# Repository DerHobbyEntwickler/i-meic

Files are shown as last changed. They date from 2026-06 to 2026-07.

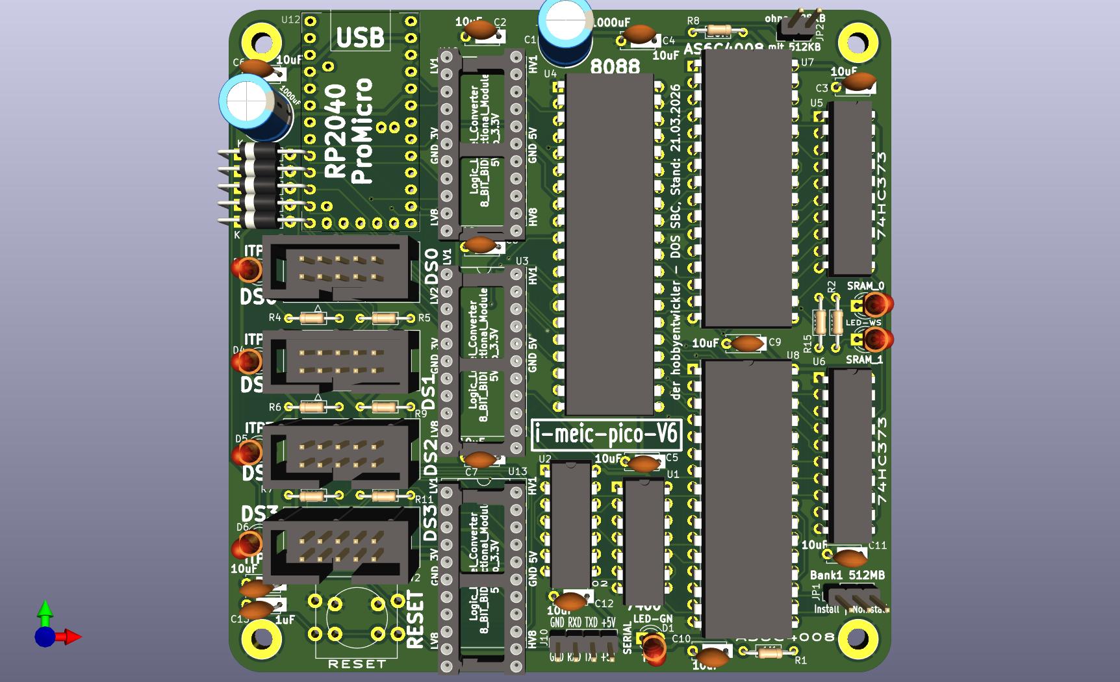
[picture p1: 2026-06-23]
10_i-meic-pico_V6/10_KiCAD/i-meic-pico_V6.jpg

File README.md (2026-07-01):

# i-meic

*(German version: [README_de.md](README_de.md))*

**The i-meic is a modular, expandable single-board computer based on the Intel 8088 CPU.**

> The hardware aims to recreate an IBM PC using the simplest possible means.
> The PC compute core consists of the 8088 CPU and 1 MB of main memory.
> All input/output is handled by a Raspberry Pi RP2040 Pro Micro.
> That is faster, simpler and cheaper than classic peripheral chips.

---

## What does "i-meic" mean?

The name is derived from the German description of the project:

| Letter | Meaning  |
|---|---|
| **i** | (**i**)ntel 8088 |
| **m** | (**m**)odular|
| **e** | (**e**)xpandable |
| **i** | s(**i**)ngle-board |
| **c** | (**c**)omputer |

---

## Concept in brief

Classic 8088 systems require a large number of peripheral chips
(clock generator, bus drivers, interrupt controller, DMA, floppy/HDD
controller, video, keyboard, etc.). The i-meic replaces this entire set of
peripherals with **a single microcontroller**: the Raspberry Pi Pico.

**The PC compute core consists of:**

- **1× Intel 8088 CPU** (16-bit, 20 address lines)
- **2× SRAM of 512 KByte each** → together **1 MByte** (the maximum of the
  8088 address space)

**The Raspberry Pi RP2040 Pro Micro (ARM Cortex-M0+) takes care of:**

- **clock generation** for the 8088 CPU (single-step / clocked operation)
- **loading the BIOS** into SRAM at startup
- the **complete I/O processing** (every read/write access to an I/O port
  is intercepted and serviced by the Pico)
- the **serial connection** to a host PC (screen, keyboard and drives are
  virtualized over the console)
- the **ITP3 interface** for modular expansion

This architecture is unusually powerful because the Pico runs at a
significantly higher clock frequency than the historic 8088 peripherals and
can therefore handle I/O operations very quickly.

---

## System and data flow

This is how a runnable DOS computer is created from source code:

```
   ┌────────────────────────────────────────────────────────────────┐
   │  70_RON-BIOS-NASM …  BIOS.ASM  (8088 assembler, NASM)          │
   │        │  nasm -f bin                                          │
   │        ▼                                                       │
   │     BIOS.BIN  (pure 8088 binary BIOS, segment F800:0000)       │
   │        │  COM2INC  (see 60_FPC_Lazarus/25_LAZ_CLI64_COM2INC)   │
   │        ▼                                                       │
   │     BIOS.INC  (Pascal byte array  BIOS_ARR[…])                 │
   └────────┬───────────────────────────────────────────────────────┘
            │  gets embedded into the Pico firmware
            ▼
   ┌────────────────────────────────────────────────────────────────┐
   │  10_…/20_Lazarus_PICO…  Firmware (Free Pascal / RP2040)        │
   │        │  Lazarus / FPC                                        │
   │        ▼                                                       │
   │     imeic_dos.uf2   →   flash onto the Raspberry Pi Pico       │
   └────────┬───────────────────────────────────────────────────────┘
            │  Pico boots:
            │  1. loads BIOS_ARR into SRAM (F800:0000)
            │  2. clocks the 8088 CPU
            │  3. services all I/O requests (IORQ)
            ▼
   ┌────────────────────────────────────────────────────────────────┐
   │  i-meic board  (8088 + 2×512 KB SRAM)  ←── serial ───┐         │
   └──────────────────────────────────────────────────────┼─────────┘
                                                           │ UART 921600 Bd
   ┌───────────────────────────────────────────────────────▼────────┐
   │  60_…/20_LAZ_Console64 …  CONSOLE64  (host PC, Win64/Linux)    │
   │  provides screen, keyboard and drive images:                  │
   │    BOOTA.IMG  (1.44 MB floppy)     BOOTC.IMG  (8 MB hard disk) │
   └────────────────────────────────────────────────────────────────┘
```

---

## Repository structure

| Folder | Contents |
|---|---|
| [`10_i-meic-pico_V6/`](10_i-meic-pico_V6/) | The actual i-meic board: KiCAD hardware **and** Pico firmware (ARM cross-compiler, I/O interface for DOS) |
| [`10_i-meic-pico_V6/10_KiCAD/`](10_i-meic-pico_V6/10_KiCAD/) | KiCAD project, schematic, layout, Gerber data for PCB manufacturing |
| [`10_i-meic-pico_V6/20_Lazarus_PICO_i-meic-pico_V6_DOS/`](10_i-meic-pico_V6/20_Lazarus_PICO_i-meic-pico_V6_DOS/) | Source code of the Pico firmware for the **ARM cross-compiler** (Free Pascal / Lazarus). The I/O interface here is designed for **DOS**. |
| [`60_FPC_Lazarus/`](60_FPC_Lazarus/) | Host PC tools (Free Pascal / Lazarus) for Windows & Linux |
| [`60_FPC_Lazarus/20_LAZ_Console64_GUI64_Win64_Linux/`](60_FPC_Lazarus/20_LAZ_Console64_GUI64_Win64_Linux/) | **CONSOLE64** – terminal/console program for all i-meic (central tool) |
| [`60_FPC_Lazarus/25_LAZ_CLI64_COM2INC/`](60_FPC_Lazarus/25_LAZ_CLI64_COM2INC/) | **COM2INC** – command-line tool that converts a binary file into a Pascal/NASM include (byte array) |
| [`70_RON-BIOS-NASM_i-meic_WIN_Linux/`](70_RON-BIOS-NASM_i-meic_WIN_Linux/) | **RON-BIOS** – the 8088 BIOS in NASM assembler including build scripts |

>
> **Operating-system variants of the firmware:** For the **i-meic board**
> there are several firmware variants that differ only in the I/O interface –
> currently **DOS** (`…_DOS`) and **CP/M-86** (`…_CPM86`). The hardware and the
> ARM cross-compiler are identical in each case.

---

## Quick start

### 1. Have the PCB manufactured
The ready-to-use Gerber data is located at
`10_i-meic-pico_V6/10_KiCAD/gerber_i-meic-pico_V6.zip` and can be uploaded
directly to a PCB manufacturer. The schematic and layout for further
development are in the same folder as a KiCAD project.

### 2. Flash the Pico firmware
Copy `imeic_dos.uf2` onto the Raspberry Pi Pico (BOOTSEL mode).

### 3. Start the console and connect
Start `CONSOLE64` (in the folder
`60_FPC_Lazarus/20_LAZ_Console64_GUI64_Win64_Linux/bin/`), set the correct
COM port and 921600 baud, then power up the i-meic.

---

## Requirements

- **Hardware:** Intel 8088, 2× SRAM (512 KByte), Raspberry Pi Pico or a
  compatible RP2040 module (footprints for several variants are provided),
  serial connection to the host
- **Software (development):**
  - [KiCAD](https://www.kicad.org/) for the hardware
  - [Lazarus / Free Pascal](https://www.lazarus-ide.org/) including the
    **ARM cross-toolchain** for the RP2040 (the Pico is an ARM
    microcontroller); the firmware runs "bare-metal" on the Pico
  - RP2040 libraries by **Michael Ring** as a basis (included in the `units/`
    folder, **adapted for this project** – see the warning below), original:
    <https://github.com/michael-ring/pico-fpcexamples>
  - [NASM](https://www.nasm.us/) for the BIOS (binaries are included)

---

## Acknowledgements / third parties

- The Free Pascal libraries for the RP2040 come from **Michael Ring**:
  <https://github.com/michael-ring/pico-fpcexamples>. They were an
  **important basis** for this Pico/RP2040 variant.
  ⚠️ The libraries shipped in the `units/` folder have been **modified and
  adapted** for this project and **must not** be replaced by the current
  upstream version (otherwise compilation errors will occur).
- **NASM** is used to assemble the 8088 BIOS (see `LICENSE_NASM.TXT`).

---

## License

This project is licensed under the **GNU General Public License v3.0** – see
[`LICENSE`](LICENSE). The BIOS and COM2INC additionally include the NASM
license (`LICENSE_NASM.TXT`) for the bundled NASM binaries.

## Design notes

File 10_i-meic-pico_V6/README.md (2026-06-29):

# 10_i-meic-pico_V6 — The i-meic board (hardware & firmware)

This folder contains **one complete i-meic variant**: the hardware (KiCAD)
and the matching Pico firmware for DOS operation.

The suffix **`pico_V6`** denotes hardware revision 6 of the board, in which
all I/O is handled by a **Raspberry Pi Pico (RP2040)**.

*(Deutsche Version: [README_de.md](README_de.md))*

## Contents

| Subfolder | Description |
|---|---|
| [`10_KiCAD/`](10_KiCAD/) | KiCAD project: schematic, PCB layout, Gerber data and component library. The PCB can be ordered **and** developed further here. |
| [`20_Lazarus_PICO_i-meic-pico_V6_DOS/`](20_Lazarus_PICO_i-meic-pico_V6_DOS/) | Source of the **Pico firmware** for the **ARM cross-compiler** (Free Pascal / Lazarus, "bare-metal" on the RP2040). The I/O interface here is built for **DOS**. Produces the `imeic_dos.uf2` for flashing the Pico. |

> **About the firmware folder name:** `Lazarus_PICO` refers to the Free
> Pascal / Lazarus **cross-compiler for the ARM core** of the RP2040 (the
> Pico is an ARM microcontroller, not x86). The suffix `…_DOS` refers to the
> **functionality of the I/O interface** for the SBC, which is built for DOS.
>
> **Further operating-system variant (same board):** For the same board there
> is a version with an I/O interface for **CP/M-86**
> (`Lazarus_PICO_i-meic-pico_V6_CPM86`). The hardware and the ARM
> cross-compiler stay the same; only the I/O functionality is tailored to the
> respective operating system.

## How it fits together

The hardware from `10_KiCAD` and the firmware from
`20_Lazarus_PICO_i-meic-pico_V6_DOS` belong directly together:

1. The PCB is manufactured according to the KiCAD/Gerber data and populated.
2. The firmware is compiled and flashed onto the Raspberry Pi Pico.
3. At startup the Pico loads the BIOS into the SRAM, clocks the 8088 CPU and
   services all of its I/O.

Screen, keyboard and drives are provided over the serial interface by the
host program **CONSOLE64**
(`60_FPC_Lazarus/20_LAZ_Console64_GUI64_Win64_Linux/`).

> The BIOS used here is built from the folder
> `70_RON-BIOS-NASM_i-meic_WIN_Linux/` and embedded into the firmware as
> `BIOS.INC`.

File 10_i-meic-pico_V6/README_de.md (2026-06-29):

# 10_i-meic-pico_V6 — Das i-meic-Board (Hardware & Firmware)

*(English version: [README.md](README.md))*

Dieser Ordner enthält **eine vollständige i-meic-Variante**: die Hardware
(KiCAD) und die dazu passende Pico-Firmware für den DOS-Betrieb.

Der Zusatz **`pico_V6`** bezeichnet die Hardware-Revision 6 des Boards, bei
der die gesamte I/O über einen **Raspberry Pi Pico (RP2040)** läuft.

## Inhalt

| Unterordner | Beschreibung |
|---|---|
| [`10_KiCAD/`](10_KiCAD/) | KiCAD-Projekt: Schaltplan, Platinen-Layout, Gerber-Daten und Bauteil-Bibliothek. Hier kann die Leiterplatte in Auftrag gegeben **und** weiterentwickelt werden. |
| [`20_Lazarus_PICO_i-meic-pico_V6_DOS/`](20_Lazarus_PICO_i-meic-pico_V6_DOS/) | Quelltext der **Pico-Firmware** für den **ARM-Cross-Compiler** (Free Pascal / Lazarus, „bare-metal" auf dem RP2040). Die I/O-Schnittstelle ist hier für **DOS** ausgelegt. Erzeugt die `imeic_dos.uf2` zum Flashen des Pico. |

> **Zur Namensgebung des Firmware-Ordners:** `Lazarus_PICO` steht für den
> Free-Pascal-/Lazarus-**Cross-Compiler für den ARM-Kern** des RP2040 (der
> Pico ist ein ARM-Mikrocontroller, kein x86). Der Zusatz `…_DOS` bezieht
> sich auf die **Funktionalität der I/O-Schnittstelle** für den SBC, die für
> DOS erstellt ist.
>
> **Weitere Betriebssystem-Variante (gleiches Board):** Für dasselbe Board
> existiert eine Version mit I/O-Schnittstelle für **CP/M-86**
> (`Lazarus_PICO_i-meic-pico_V6_CPM86`). Hardware und ARM-Cross-Compiler
> bleiben gleich, nur die I/O-Funktionalität ist auf das jeweilige
> Betriebssystem zugeschnitten.

## Zusammenspiel

Die Hardware aus `10_KiCAD` und die Firmware aus
`20_Lazarus_PICO_i-meic-pico_V6_DOS` gehören direkt zusammen:

1. Die Leiterplatte wird nach den KiCAD-/Gerber-Daten gefertigt und bestückt.
2. Die Firmware wird übersetzt und auf den Raspberry Pi Pico geflasht.
3. Der Pico lädt beim Start das BIOS in den SRAM, taktet die 8088-CPU und
   bedient deren gesamte I/O.

Bildschirm, Tastatur und Laufwerke werden über die serielle Schnittstelle
vom Host-Programm **CONSOLE64**
(`60_FPC_Lazarus/20_LAZ_Console64_GUI64_Win64_Linux/`) bereitgestellt.

> Das hier verwendete BIOS wird aus dem Ordner
> `70_RON-BIOS-NASM_i-meic_WIN_Linux/` gebaut und als `BIOS.INC` in die
> Firmware eingebettet.

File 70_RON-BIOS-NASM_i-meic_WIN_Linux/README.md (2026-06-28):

# 70_RON-BIOS-NASM_i-meic_WIN_Linux — RON-BIOS (8086 BIOS)

The **RON-BIOS** is the BIOS of the i-meic, written in **8086 assembly for
NASM**. It is assembled into a binary BIOS and then embedded into the Pico
firmware, which loads it into the SRAM at startup.

- Target processor: **8086** (`BITS 16`, `CPU 8086`)
- BIOS segment: **`F800:0000`**, stack at `FF00`
- Builds on **Windows and Linux** (NASM binaries are included)

*(Deutsche Version: [README_de.md](README_de.md))*

## Structure

The BIOS is built modularly from several assembly files that are combined in
`BIOS.ASM`:

| File | Contents |
|---|---|
| `BIOS.ASM` | Main/entry file, includes the modules. |
| `BDA.ASM` | BIOS Data Area. |
| `EQUDISK.ASM` | Constants/definitions for drives. |
| `INT08.ASM` | Timer interrupt (system tick). |
| `INT10.ASM` | Video services (screen output). |
| `INT13.ASM` | Floppy/hard-disk services. |
| `INT16.ASM` | Keyboard services. |
| `INT1A.ASM` | Time/date (RTC). |
| `INT02.ASM`, `INT18.ASM`, `INT1D.txt`, `INT33.ASM` | Further interrupts (incl. mouse, INT 33h). |
| `VGABIOS.ASM` | Video-BIOS part. |
| `DEBUG.ASM` | Debugging helpers. |
| `BIOS.INC` | Generated include (intermediate state, built via COM2INC). |
| `BIOS.BIN` | **Finished binary BIOS** (result of NASM). |

## Bundled tools

| File | Purpose |
|---|---|
| `nasm.exe` / `nasm` | NASM assembler for Windows and Linux. |
| `COM2INC.exe` / `COM2INC` | Converts `BIOS.BIN` into `BIOS.INC` (byte array). |
| `run_win.bat` | Build script for Windows. |
| `run_linux.sh` | Build script for Linux. |
| `LICENSE_NASM.TXT` | License of NASM. |

## Building the BIOS

**Windows:** run `run_win.bat`.
**Linux:** run `run_linux.sh`.

In essence both perform the same steps:

```
nasm -f bin BIOS.ASM -o BIOS.BIN          # assemble the 8086 BIOS
COM2INC BIOS.BIN BIOS.INC Laenge_BIOS_Array BIOS_ARR   # convert to byte array
```

Afterwards `BIOS.INC` is copied into the Pico firmware under
`10_i-meic-pico_V6/20_Lazarus_PICO_i-meic-pico_V6_DOS/20_i-meic-pico_V6_DOS/`
(the Windows script does this automatically). Then recompile the firmware so
that the updated BIOS takes effect.

> **Connection to the hardware:** The I/O command codes defined in the BIOS
> (e.g. `IORQ_CONIN`, `IORQ_READ`, `IORQ_VIDEO_SEND`) correspond to the
> functions serviced by the Pico firmware. The BIOS and firmware must
> therefore match each other.

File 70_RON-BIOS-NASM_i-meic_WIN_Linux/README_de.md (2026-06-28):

# 70_RON-BIOS-NASM_i-meic_WIN_Linux — RON-BIOS (8086-BIOS)

*(English version: [README.md](README.md))*

Das **RON-BIOS** ist das BIOS des i-meic, geschrieben in **8086-Assembler
für NASM**. Es wird zu einem Binär-BIOS übersetzt und anschließend in die
Pico-Firmware eingebettet, die es beim Start in den SRAM lädt.

- Zielprozessor: **8086** (`BITS 16`, `CPU 8086`)
- BIOS-Segment: **`F800:0000`**, Stack bei `FF00`
- Build unter **Windows und Linux** (NASM-Binaries liegen bei)

## Aufbau

Das BIOS ist modular aus mehreren Assembler-Dateien aufgebaut, die in
`BIOS.ASM` zusammengeführt werden:

| Datei | Inhalt |
|---|---|
| `BIOS.ASM` | Haupt-/Einstiegsdatei, bindet die Module ein. |
| `BDA.ASM` | BIOS Data Area. |
| `EQUDISK.ASM` | Konstanten/Definitionen für Laufwerke. |
| `INT08.ASM` | Timer-Interrupt (System-Tick). |
| `INT10.ASM` | Video-Dienste (Bildschirmausgabe). |
| `INT13.ASM` | Disketten-/Festplatten-Dienste. |
| `INT16.ASM` | Tastatur-Dienste. |
| `INT1A.ASM` | Uhrzeit/Datum (RTC). |
| `INT02.ASM`, `INT18.ASM`, `INT1D.txt`, `INT33.ASM` | Weitere Interrupts (u. a. Maus, INT 33h). |
| `VGABIOS.ASM` | Video-BIOS-Anteil. |
| `DEBUG.ASM` | Debug-Hilfen. |
| `BIOS.INC` | Erzeugtes Include (Zwischenstand, wird per COM2INC gebaut). |
| `BIOS.BIN` | **Fertiges Binär-BIOS** (Ergebnis von NASM). |

## Mitgelieferte Werkzeuge

| Datei | Zweck |
|---|---|
| `nasm.exe` / `nasm` | NASM-Assembler für Windows bzw. Linux. |
| `COM2INC.exe` / `COM2INC` | Wandelt `BIOS.BIN` in `BIOS.INC` (Byte-Array). |
| `run_win.bat` | Build-Skript für Windows. |
| `run_linux.sh` | Build-Skript für Linux. |
| `LICENSE_NASM.TXT` | Lizenz von NASM. |

## BIOS bauen

**Windows:** `run_win.bat` ausführen.
**Linux:** `run_linux.sh` ausführen.

Beide führen im Kern dieselben Schritte aus:

```
nasm -f bin BIOS.ASM -o BIOS.BIN          # 8086-BIOS assemblieren
COM2INC BIOS.BIN BIOS.INC Laenge_BIOS_Array BIOS_ARR   # in Byte-Array wandeln
```

Anschließend wird `BIOS.INC` in die Pico-Firmware unter
`10_i-meic-pico_V6/20_Lazarus_PICO_i-meic-pico_V6_DOS/20_i-meic-pico_V6_DOS/`
kopiert (das Windows-Skript erledigt das automatisch). Danach die Firmware
neu übersetzen, damit das aktualisierte BIOS wirksam wird.

> **Verbindung zur Hardware:** Die im BIOS definierten I/O-Befehlscodes
> (z. B. `IORQ_CONIN`, `IORQ_READ`, `IORQ_VIDEO_SEND`) entsprechen den
> Funktionen, die die Pico-Firmware bedient. BIOS und Firmware müssen daher
> zueinander passen.

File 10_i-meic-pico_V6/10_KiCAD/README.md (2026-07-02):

# 10_KiCAD — Hardware design of the i-meic board (KiCAD)

This folder contains everything needed to **have the i-meic PCB
manufactured** and to **develop the hardware further**.

*(Deutsche Version: [README_de.md](README_de.md))*

## Most important files

| File / folder | Purpose |
|---|---|
| `gerber_i-meic-pico_V6.zip` | **Fabrication data (Gerber + drill).** Can be uploaded directly to a PCB manufacturer. |
| `i-meic-pico_V6.pdf` | Schematic / layout as PDF for viewing and printing. |
| `i-meic-pico_V6.svg` | Vector view of the board. |
| `i-meic-pico_V6.jpg` | Image of the board for a quick overview. |
| `i-meic-pico_V6/` | The actual **KiCAD project** (see below). |

## KiCAD project folder `i-meic-pico_V6/`

| File | Meaning |
|---|---|
| `i-meic-pico_V6.kicad_pro` | KiCAD project file (open the project with this). |
| `i-meic-pico_V6.kicad_sch` | Schematic. |
| `i-meic-pico_V6.kicad_pcb` | PCB layout. |
| `i-meic-pico_V6.kicad_prl` | Local project settings. |
| `board-library/` | **Project-specific component library** with symbols (`.kicad_sym`) and footprints (`.pretty/*.kicad_mod`) – for RP2040 modules, SRAM, LCDs, ITP3 connectors, switches and more. |

## Having the PCB manufactured

1. Upload `gerber_i-meic-pico_V6.zip` unchanged to a PCB manufacturer.
2. Choose the usual parameters (e.g. 2 layers, 1.6 mm, HASL/ENIG).
3. After receiving the board, populate it according to the schematic.

## Developing further

Open the project with **KiCAD** via `i-meic-pico_V6.kicad_pro`. For the
project-specific parts to load correctly, keep the `board-library/` folder as
a library path relative to the project.

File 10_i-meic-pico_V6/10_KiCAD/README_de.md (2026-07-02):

# 10_KiCAD — Hardware-Design des i-meic-Boards (KiCAD)

*(English version: [README.md](README.md))*

Hier liegen alle Dateien, um die Leiterplatte des i-meic **fertigen zu
lassen** und um die Hardware **selbst weiterzuentwickeln**.

## Wichtigste Dateien

| Datei / Ordner | Zweck |
|---|---|
| `gerber_i-meic-pico_V6.zip` | **Fertigungsdaten (Gerber + Bohrdaten).** Direkt beim Leiterplattenhersteller hochladbar. |
| `i-meic-pico_V6.pdf` | Schaltplan / Layout als PDF zum Ansehen und Drucken. |
| `i-meic-pico_V6.svg` | Vektor-Ansicht des Boards. |
| `i-meic-pico_V6.jpg` | Bild des Boards zur schnellen Übersicht. |
| `i-meic-pico_V6/` | Das eigentliche **KiCAD-Projekt** (siehe unten). |

## KiCAD-Projektordner `i-meic-pico_V6/`

| Datei | Bedeutung |
|---|---|
| `i-meic-pico_V6.kicad_pro` | KiCAD-Projektdatei (hiermit das Projekt öffnen). |
| `i-meic-pico_V6.kicad_sch` | Schaltplan. |
| `i-meic-pico_V6.kicad_pcb` | Platinen-Layout. |
| `i-meic-pico_V6.kicad_prl` | Lokale Projekteinstellungen. |
| `board-library/` | **Projekteigene Bauteil-Bibliothek** mit Symbolen (`.kicad_sym`) und Footprints (`.pretty/*.kicad_mod`) – u. a. für RP2040-Module, SRAM, LCDs, ITP3-Stecker, Schalter und mehr. |

## Leiterplatte fertigen lassen

1. `gerber_i-meic-pico_V6.zip` unverändert beim Leiterplattenhersteller
   hochladen.
2. Übliche Parameter wählen (z. B. 2 Lagen, 1,6 mm, HASL/ENIG).
3. Nach Erhalt der Platine gemäß Schaltplan bestücken.

## Weiterentwickeln

Das Projekt mit **KiCAD** über `i-meic-pico_V6.kicad_pro` öffnen. Damit die
projekteigenen Bauteile korrekt geladen werden, sollte der Ordner
`board-library/` als Bibliothekspfad relativ zum Projekt erhalten bleiben.

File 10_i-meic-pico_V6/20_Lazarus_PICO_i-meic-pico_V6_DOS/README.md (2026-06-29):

# 20_Lazarus_PICO_i-meic-pico_V6_DOS — Pico firmware (I/O interface for DOS)

Source of the **firmware for the Raspberry Pi Pico (RP2040)** on the i-meic
board. The firmware turns the 8088 core into a working computer by taking
over all of its input/output.

*(Deutsche Version: [README_de.md](README_de.md))*

## About the folder name

The name consists of two parts:

- **`Lazarus_PICO`** — The RP2040 of the Raspberry Pi Pico is an **ARM
  microcontroller** (Cortex-M0+). This folder therefore contains the source
  for the **Lazarus / Free Pascal cross-compiler for ARM**, i.e.
  "bare-metal" Pascal that runs directly on the Pico (not classic desktop
  Lazarus).
- **`i-meic-pico_V6_DOS`** — refers to the **functionality of the I/O
  interface** for the SBC. This build is made for the **DOS** operating
  system.

> **Sister variant:** For **the same board** there is a version with an I/O
> interface for **CP/M-86**: `Lazarus_PICO_i-meic-pico_V6_CPM86`. The hardware
> and cross-compiler are identical; only the I/O functionality is tailored to
> the respective operating system.

## Tasks of the firmware

- **Hardware initialisation** of the Pico (GPIO, UART, SPI, timer)
- **Loading the BIOS** (`BIOS.INC` → array `BIOS_ARR`) into the SRAM of the
  8088 (segment `F800:0000`)
- **Clocking the 8088 CPU** and controlling RESET, RAM enable, etc.
- **Servicing all I/O requests (IORQ)** of the CPU: console, drives, clock,
  sound, mouse … — here built for **DOS**
- **Serial communication** with the host (default: **921600 baud**)
- **ITP3 expansion bus** (device select DS0–DS3)

## Project structure

| File / folder | Meaning |
|---|---|
| `20_i-meic-pico_V6_DOS/imeic_dos.lpi` | **Lazarus project file** – open the project with this. |
| `20_i-meic-pico_V6_DOS/imeic_dos.lpr` | Main program (firmware startup sequence). |
| `20_i-meic-pico_V6_DOS/GlobalHW_U.PAS` | Hardware layer: GPIO, UART, SPI, data/address bus of the 8088. |
| `20_i-meic-pico_V6_DOS/GlobalDEF_U.PAS` | Global definitions, device constants, data structures. |
| `20_i-meic-pico_V6_DOS/BIOSAdmin_U.PAS` | Management/embedding of the BIOS and the BIOS flash. |
| `20_i-meic-pico_V6_DOS/DeviceManager_U.PAS` | Device management; services the I/O functions for the 8088 CPU. |
| `20_i-meic-pico_V6_DOS/DeviceManager_DOS_IO.INC` | I/O routines specifically for **DOS**. |
| `20_i-meic-pico_V6_DOS/DeviceManager_CPU8088.INC` | CPU-specific routines (8088 bus timing). |
| `20_i-meic-pico_V6_DOS/ITP3_SRV_U.PAS` | Server for the ITP3 expansion bus. |
| `20_i-meic-pico_V6_DOS/UART_U.PAS` | Serial interface. |
| `20_i-meic-pico_V6_DOS/SysTick_U.PAS`, `SysUtils_U.PAS` | Time/utility functions. |
| `20_i-meic-pico_V6_DOS/BIOS.INC` | **Embedded 8086 BIOS** as a byte array (generated from `70_RON-BIOS-NASM…`). |
| `20_i-meic-pico_V6_DOS/bin/imeic_dos.uf2` | **Finished firmware** for flashing the Pico. Also `.elf`, `.hex`, `.bin`. |
| `units/` | **Libraries for the ARM cross-compiler** – see the next section. |

## The `units/` folder (adapted libraries by Michael Ring)

The `units/` subfolder contains the **Free Pascal libraries for the RP2040 by
Michael Ring**. They were an **important foundation** for developing these
cross-compiled sources – without them this Pico/RP2040 variant would not
exist. They provide hardware access (GPIO, UART, SPI, I²C, timer, multicore …)
as well as various drivers (displays such as SSD1306 / ST7735 / ST7789, fonts,
GPS, RTC, etc.) for the ARM cross-compiler.

Original project by Michael Ring:
**https://github.com/michael-ring/pico-fpcexamples**

> ⚠️ **Important:** The units shipped here have been **modified and adapted**
> for this project (for example, some pointer usages were removed). The
> `units/` folder must **not** be replaced with the current version from the
> original repository – otherwise compilation will produce numerous errors.
> **Always use the bundled `units/` folder.**

## Build and flash

1. Open `20_i-meic-pico_V6_DOS/imeic_dos.lpi` in **Lazarus** (the Free Pascal
   **ARM cross-toolchain** for the RP2040 must be set up; the **bundled**
   units from `units/` are required – not the upstream version).
2. Compile the project → this produces `bin/imeic_dos.uf2`.
3. Connect the Pico in **BOOTSEL mode** (hold the BOOTSEL button while
   plugging it in) and copy `imeic_dos.uf2` onto the drive that appears.

## Updating the BIOS

When changing the BIOS, first rebuild it in the folder
`70_RON-BIOS-NASM_i-meic_WIN_Linux/` (produces `BIOS.INC`), copy the
`BIOS.INC` here and recompile the firmware.

> **Note:** The baud rate can be changed in `GlobalHW_U.PAS`; it must match the
> setting in CONSOLE64.

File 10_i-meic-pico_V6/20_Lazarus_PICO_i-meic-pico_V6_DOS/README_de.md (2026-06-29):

# 20_Lazarus_PICO_i-meic-pico_V6_DOS — Pico-Firmware (I/O-Schnittstelle für DOS)

*(English version: [README.md](README.md))*

Quelltext der **Firmware für den Raspberry Pi Pico (RP2040)** auf dem
i-meic-Board. Die Firmware macht aus dem 8086-Kern einen lauffähigen
Rechner, indem sie dessen gesamte Ein-/Ausgabe übernimmt.

## Zur Bedeutung des Ordnernamens

Der Name setzt sich aus zwei Teilen zusammen:

- **`Lazarus_PICO`** — Der RP2040 des Raspberry Pi Pico ist ein
  **ARM-Mikrocontroller** (Cortex-M0+). In diesem Ordner liegt daher der
  Quelltext für den **Lazarus/Free-Pascal-Cross-Compiler für ARM**, also
  „bare-metal"-Pascal, das direkt auf dem Pico läuft (kein klassisches
  Desktop-Lazarus).
- **`i-meic-pico_V6_DOS`** — bezieht sich auf die **Funktionalität der
  I/O-Schnittstelle** für den SBC. Diese Ausführung ist für das
  Betriebssystem **DOS** erstellt.

> **Schwester-Variante:** Für **dasselbe Board** gibt es eine Version mit
> einer I/O-Schnittstelle für **CP/M-86**:
> `Lazarus_PICO_i-meic-pico_V6_CPM86`. Hardware und Cross-Compiler sind
> identisch, nur die I/O-Funktionalität ist auf das jeweilige Betriebssystem
> abgestimmt.

## Aufgaben der Firmware

- **Hardware-Initialisierung** des Pico (GPIO, UART, SPI, Timer)
- **Laden des BIOS** (`BIOS.INC` → Array `BIOS_ARR`) in den SRAM des 8088
  (Segment `F800:0000`)
- **Takten der 8088-CPU** und Steuern von RESET, RAM-Enable usw.
- **Bedienen aller I/O-Anforderungen (IORQ)** der CPU: Konsole, Laufwerke,
  Uhr, Sound, Maus … — hier ausgelegt für **DOS**
- **Serielle Kommunikation** mit dem Host (Standard: **921600 Baud**)
- **ITP3-Erweiterungsbus** (Device-Select DS0–DS3)

## Projektstruktur

| Datei / Ordner | Bedeutung |
|---|---|
| `20_i-meic-pico_V6_DOS/imeic_dos.lpi` | **Lazarus-Projektdatei** – hiermit das Projekt öffnen. |
| `20_i-meic-pico_V6_DOS/imeic_dos.lpr` | Hauptprogramm (Startablauf der Firmware). |
| `20_i-meic-pico_V6_DOS/GlobalHW_U.PAS` | Hardware-Schicht: GPIO, UART, SPI, Daten-/Adressbus des 8088. |
| `20_i-meic-pico_V6_DOS/GlobalDEF_U.PAS` | Globale Definitionen, Gerätekonstanten, Datenstrukturen. |
| `20_i-meic-pico_V6_DOS/BIOSAdmin_U.PAS` | Verwaltung/Einbinden des BIOS und des BIOS-Flash. |
| `20_i-meic-pico_V6_DOS/DeviceManager_U.PAS` | Geräteverwaltung; bedient die I/O-Funktionen für die 8088-CPU. |
| `20_i-meic-pico_V6_DOS/DeviceManager_DOS_IO.INC` | I/O-Routinen speziell für **DOS**. |
| `20_i-meic-pico_V6_DOS/DeviceManager_CPU8088.INC` | CPU-spezifische Routinen (8088-Bustakt). |
| `20_i-meic-pico_V6_DOS/ITP3_SRV_U.PAS` | Server für den ITP3-Erweiterungsbus. |
| `20_i-meic-pico_V6_DOS/UART_U.PAS` | Serielle Schnittstelle. |
| `20_i-meic-pico_V6_DOS/SysTick_U.PAS`, `SysUtils_U.PAS` | Zeit-/Hilfsfunktionen. |
| `20_i-meic-pico_V6_DOS/BIOS.INC` | **Eingebettetes 8088-BIOS** als Byte-Array (aus `70_RON-BIOS-NASM…` erzeugt). |
| `20_i-meic-pico_V6_DOS/bin/imeic_dos.uf2` | **Fertige Firmware** zum Flashen des Pico. Außerdem `.elf`, `.hex`, `.bin`. |
| `units/` | **Bibliotheken für den ARM-Cross-Compiler** – siehe nächster Abschnitt. |

## Der Ordner `units/` (angepasste Bibliotheken von Michael Ring)

Der Unterordner `units/` enthält die **Free-Pascal-Bibliotheken für den
RP2040 von Michael Ring**. Sie waren eine **wichtige Grundlage** für die
Entwicklung dieser Cross-Quelltexte – ohne sie hätte es diese Variante mit
dem Pico/RP2040 nicht gegeben. Sie stellen den Hardware-Zugriff (GPIO, UART,
SPI, I²C, Timer, Multicore …) sowie diverse Treiber (Displays wie SSD1306 /
ST7735 / ST7789, Fonts, GPS, RTC u. a.) für den ARM-Cross-Compiler bereit.

Original-Projekt von Michael Ring:
**https://github.com/michael-ring/pico-fpcexamples**

> ⚠️ **Wichtig:** Die hier mitgelieferten Units wurden für dieses Projekt
> **verändert und angepasst** (z. B. wurden einige Pointer-Nutzungen
> entfernt). Der Ordner `units/` darf **auf keinen Fall** durch die aktuelle
> Version aus dem Original-Repository ersetzt werden – andernfalls kommt es
> beim Übersetzen zu zahlreichen Fehlermeldungen. Es ist **immer der
> mitgelieferte `units/`-Ordner** zu verwenden.

## Bauen und Flashen

1. `20_i-meic-pico_V6_DOS/imeic_dos.lpi` in **Lazarus** öffnen
   (Free-Pascal-**ARM-Cross-Toolchain** für den RP2040 muss eingerichtet
   sein; die **mitgelieferten** Units aus `units/` werden benötigt – nicht
   die Upstream-Version).
2. Projekt übersetzen → es entsteht `bin/imeic_dos.uf2`.
3. Pico im **BOOTSEL-Modus** anschließen (BOOTSEL-Taste beim Einstecken
   halten) und die `imeic_dos.uf2` auf das erscheinende Laufwerk kopieren.

## BIOS aktualisieren

Bei Änderungen am BIOS zuerst im Ordner
`70_RON-BIOS-NASM_i-meic_WIN_Linux/` neu bauen (erzeugt `BIOS.INC`), die
`BIOS.INC` hierher kopieren und die Firmware neu übersetzen.

> **Hinweis:** Die Baudrate lässt sich in `GlobalHW_U.PAS` umstellen; sie
> muss mit der Einstellung in CONSOLE64 übereinstimmen.

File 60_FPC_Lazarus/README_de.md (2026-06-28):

# 60_FPC_Lazarus — Host-PC-Werkzeuge (Free Pascal / Lazarus)

*(English version: [README.md](README.md))*

Dieser Ordner bündelt die **PC-Programme** rund um den i-meic, geschrieben in
**Free Pascal / Lazarus** und lauffähig unter **Windows 64-Bit und Linux**.
Sie laufen auf dem Host-Rechner, nicht auf dem i-meic selbst.

## Inhalt

| Unterordner | Programm | Zweck |
|---|---|---|
| [`20_LAZ_Console64_GUI64_Win64_Linux/`](20_LAZ_Console64_GUI64_Win64_Linux/) | **CONSOLE64** | Zentrales Terminal-/Konsolenprogramm. Stellt dem i-meic über die serielle Schnittstelle Bildschirm, Tastatur und Laufwerks-Images zur Verfügung. **Wird für alle i-meic benötigt.** |
| [`25_LAZ_CLI64_COM2INC/`](25_LAZ_CLI64_COM2INC/) | **COM2INC** | Kommandozeilen-Werkzeug, das eine Binärdatei (z. B. das BIOS) in ein Pascal-/NASM-Include mit einem Byte-Array umwandelt. |

## Hinweis zu den Konsolen

CONSOLE64 ist die hier abgelegte Konsole – es **gibt mehrere Konsolen** für
unterschiedliche i-meic-Varianten, die nach und nach ergänzt werden. Die
Nummerierung (`20_`, `25_`, …) lässt dafür bewusst Platz.

## Bauen

Alle Programme lassen sich mit **Lazarus** über die jeweilige `*.lpi`-Datei
öffnen und übersetzen. Vorkompilierte Binaries (`.exe` für Windows, die
ausführbare Datei ohne Endung für Linux) liegen zur direkten Nutzung bei.

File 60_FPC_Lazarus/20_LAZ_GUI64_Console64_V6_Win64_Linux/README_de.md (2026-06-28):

# 20_LAZ_Console64_GUI64_Win64_Linux — CONSOLE64

*(English version: [README.md](README.md))*

**CONSOLE64** ist das zentrale Host-Programm für den i-meic. Es verbindet
sich über die serielle Schnittstelle mit dem Board und stellt ihm die
gesamte „sichtbare" Peripherie bereit:

- **Bildschirm / Video-Terminal** (mit Codepage-437-Zeichensatz)
- **Tastatur**
- **Laufwerke** als Disk-Images (Diskette und Festplatte)

Ohne diese Konsole hat der i-meic weder Anzeige noch Eingabe – sie wird
daher **für alle i-meic benötigt**. Lauffähig unter **Windows 64-Bit und
Linux** (GUI-Anwendung auf LCL-Basis).

## Ordnerstruktur

| Ordner / Datei | Bedeutung |
|---|---|
| `bin/CONSOLE64.exe` | Ausführbares Programm (Windows). |
| `bin/CONSOLE64` | Ausführbares Programm (Linux). |
| `bin/CONSOLE64.ini` | Konfiguration: COM-Port, Baudrate, Schrift, Sprache, Logging. |
| `bin/IMAGE_FDD/BOOTA.IMG` | Disketten-Image (1,44 MB) – Laufwerk A:. |
| `bin/IMAGE_HDD/BOOTC.IMG` | Festplatten-Image (8 MB) – Laufwerk C:. |
| `src/` | Lazarus-Quelltext. |

### Wichtige Quelldateien (`src/`)

| Datei | Inhalt |
|---|---|
| `CONSOLE64.lpi` / `.lpr` | Lazarus-Projekt und Hauptprogramm. |
| `MainUnit.pas` / `.lfm` | Hauptfenster und Programmlogik. |
| `Unit_CONS.pas` / `.lfm` | Konsolen-/Terminal-Fenster. |
| `Video_Send.INC` | Aufbereitung der Videoausgabe zum/vom i-meic. |
| `Codepage437.INC` | DOS-Zeichensatz (Codepage 437). |
| `Keyboard.INC` | Tastaturbehandlung. |
| `language_u.pas`, `language_de.INC`, `language_en.INC` | Mehrsprachigkeit (Deutsch/Englisch). |
| `synaser/` | Serielle Bibliothek (Synaser) für die COM-Port-Kommunikation. |
| `windos.pas` | Hilfsroutinen. |

## Bedienung

1. Programm starten (`CONSOLE64.exe` bzw. `./CONSOLE64`).
2. In den Einstellungen den richtigen **COM-Port** und die **Baudrate**
   wählen. Die Baudrate muss mit der Firmware übereinstimmen
   (Standard der Firmware: **921600 Baud**).
3. Bei Bedarf die Disk-Images in `IMAGE_FDD/` bzw. `IMAGE_HDD/` zuordnen.
4. Den i-meic mit Strom versorgen – die Konsole zeigt die Ausgabe an und
   leitet Tastatureingaben weiter.

Die Einstellungen werden in `CONSOLE64.ini` gespeichert.

> **Tipp:** Eigene DOS-Disketten/Festplatten lassen sich durch Austauschen
> der `BOOTA.IMG` / `BOOTC.IMG` einbinden (gleiche Image-Größe beibehalten).

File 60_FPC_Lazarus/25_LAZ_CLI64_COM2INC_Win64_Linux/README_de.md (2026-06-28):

# 25_LAZ_CLI64_COM2INC — COM2INC

*(English version: [README.md](README.md))*

**COM2INC** ist ein kleines Kommandozeilen-Werkzeug (Free Pascal / Lazarus),
das eine **Binärdatei in ein Include-File mit einem Byte-Array** umwandelt.
Damit lässt sich z. B. das fertige BIOS-Binär (`BIOS.BIN`) als Pascal-Array
in die Pico-Firmware einbetten.

Lauffähig unter **Windows 64-Bit und Linux**.

## Funktion

```
COM2INC  <Eingabe.BIN>  <Ausgabe.INC>  <Längen-Konstante>  <Array-Name>  [CLEAR]
```

| Parameter | Bedeutung |
|---|---|
| `Eingabe.BIN` | beliebige Binärdatei (z. B. `BIOS.BIN`, `CPD5.COM`). |
| `Ausgabe.INC` | erzeugtes Include mit dem Byte-Array. |
| `Längen-Konstante` | Name der erzeugten Längenkonstante (z. B. `Laenge_BIOS_Array`). |
| `Array-Name` | Name des erzeugten Arrays (z. B. `BIOS_ARR`). |
| `CLEAR` | optional; bereinigt/initialisiert die Ausgabe. |

**Beispiel** (siehe `run_win.bat`):

```
COM2INC.exe CPD5.COM CPD5.INC Laenge_BIOS_Array BIOS_ARR CLEAR
```

Ergebnis ist eine `.INC`-Datei der Form
`BIOS_ARR : array[0..Laenge_BIOS_Array] of Byte = ( … );`, die per
`{$I …}` in den Pascal-Quelltext eingebunden werden kann.

## Inhalt des Ordners

| Datei | Bedeutung |
|---|---|
| `COM2INC.lpi` / `.lpr` | Lazarus-Projekt und Quelltext. |
| `COM2INC.exe` | Ausführbares Programm (Windows). |
| `COM2INC` | Ausführbares Programm (Linux). |
| `CPD5.COM` / `CPD5.INC` | Beispiel: Eingabe-Binär und erzeugtes Include. |
| `run_win.bat` / `run_linux.sh` | Aufruf-Beispiele für Windows bzw. Linux. |
| `LICENSE_NASM.TXT` | Lizenz der mitgelieferten NASM-Komponenten. |

## Bezug zum BIOS

Dasselbe Werkzeug wird im Ordner `70_RON-BIOS-NASM_i-meic_WIN_Linux/`
verwendet, um aus `BIOS.BIN` die `BIOS.INC` für die Firmware zu erzeugen.

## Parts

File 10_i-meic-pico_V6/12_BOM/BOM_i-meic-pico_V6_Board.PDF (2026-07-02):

# Bill of Materials (BOM)

### i-meic-pico_V6 Board

DOS PC with an 8088 single-board computer (SBC)

Project: i-meic – single-board DOS PC As of: Juli 2026 / July 2026 https://github.com/DerHobbyEntwickler/i-meic

Bill of Materials — i-meic-pico_V6 Board | https://github.com/DerHobbyEntwickler/i-meic | Page 1

Processing core: CPU Intel 80C88 + 2× SRAM AS6C4008 (512 KB each, 1 MB total max.)

Line items: 22 · Total parts: 56

Part | Qty | Value | Remarks | Note | Datasheet
C1, C14 | 2 | 470uF/10V or 1000uF/10V | Electrolytic capacitor, radial, D8.0 mm, P3.50 mm | H01 | Datasheet (https://www.reichelt.de/de/de/shop/produkt/elko_radial_1_0_mf_10_v_105_c_low_esr-200069)
C2, C3, C4, C5, C6, C7, C8, C9, C10, C11, C12, C13, C18 | 13 | 1uF/50V or 10uF/50V | Monolithic ceramic capacitor, pitch 2.5 mm to 5 mm | H02 | Datasheet (https://www.conrad.de/de/p/tancap-ct4-0805y105m500a1-keramik-kondensator-tht-1-f-50-v-20-b-x-h-4-2-mm-x-25-mm-1-st-1578616.html)
D1 | 1 | LED green, UART | Light-emitting diode, 3 mm or 5 mm | H03 | Datasheet (https://www.reichelt.de/de/de/shop/produkt/led_3mm_bedrahtet_gruen_50_mcd_60_-361591)
D2, D17 | 2 | LED white, SRAM | Light-emitting diode, 3 mm or 5 mm | — | Datasheet (https://www.reichelt.de/de/de/shop/produkt/led_3mm_bedrahtet_gruen_50_mcd_60_-361591)
D3, D4, D5, D6 | 4 | LED blue, ITP3 | Light-emitting diode, 3 mm or 5 mm | — | Datasheet (https://www.reichelt.de/de/de/shop/produkt/led_3mm_bedrahtet_gruen_50_mcd_60_-361591)
D7, D8, D9, D10, D11 | 5 | 1N4001 | Diode 1N4001 | H04 | Datasheet (https://www.reichelt.de/de/de/shop/produkt/gleichrichterdiode_50_v_1_a_do-41-1723)
J10 | 1 | Connector for serial adapter | Pin header 2.54 mm, single row, 4 pins | H05 | Datasheet (https://www.reichelt.de/de/de/shop/produkt/stiftleisten_2_54_mm_1x36_gerade-119890)
JP1 | 1 | Jumper connector, 3 pins | Pin header 2.54 mm, single row, 3 pins | — | Datasheet (https://www.reichelt.de/de/de/shop/produkt/stiftleisten_2_54_mm_1x36_gerade-119890)
JP2 | 1 | Jumper connector, 2 pins | Pin header 2.54 mm, single row, 2 pins | — | Datasheet (https://www.reichelt.de/de/de/shop/produkt/stiftleisten_2_54_mm_1x36_gerade-119890)
J_DS0, J_DS1, J_DS2, J_DS3 | 4 | Connector for ITP3 cable, dual row | Box header, 10-pin, straight, dual row | H06 | Datasheet (https://www.reichelt.de/de/de/shop/produkt/wannenstecker_10-polig_gerade-22816)
R1 | 1 | 1K | Resistor, carbon film, 1.0 kOhm, 0207, 250 mW, 5 % | H07 | Datasheet (https://www.reichelt.de/de/de/shop/produkt/widerstand_kohleschicht_1_0_kohm_0207_250_mw_5_-1315)
R2, R15 | 2 | 6.8K | Resistor, carbon film, 6.8 kOhm, 0207, 250 mW, 5 % | — | —
R4, R5, R6, R7 | 4 | 2.2K | Resistor, carbon film, 2.2 kOhm, 0207, 250 mW, 5 % | — | —
R8, R9, R11 | 3 | 10K | Resistor, carbon film, 10 kOhm, 0207, 250 mW, 5 % | H08 | —
SW2 | 1 | Reset button | Tact switch, PCB mount, 1 NO contact, 12 x 12 x 4.3 mm | — | Datasheet (https://www.reichelt.de/de/de/shop/produkt/kurzhubtaster_printmontage_1_schliesser_12_x_12_x_4_3_mm-424572)
U1 | 1 | IC 74HC00 | Quad 2-input NAND gate, 2 … 6 V, DIL-14 | H09 | Datasheet (https://www.reichelt.de/de/de/shop/produkt/4-fach_2_eingangs-nand-gatter_2_6_v_dil-14-3119)
U2 | 1 | IC 74HC02 | NOR gate, 2-input, 2 … 6 V, DIL-14 | — | Datasheet (https://www.reichelt.de/de/de/shop/produkt/nor-gate_2-input_2_6_v_dil-14-3121)
U3, U10, U13 | 3 | 8-channel bidirectional logic level shifter (3.3V ↔ 5V) | 8-channel bidirectional logic level shifter module (3.3V ↔ 5V) | — | Datasheet (https://www.ebay.de/itm/263540322019?chn=ps&_ul=DE&google_free_listing_action=view_item)
U4 | 1 | IC CPU 80C88 | CPU Intel 80C88 or compatible | H10 | Datasheet (https://datasheets.chipdb.org/Harris/80c88.pdf)
U5, U6 | 2 | IC 74HC373 | Latch, 3-state, 2 … 6 V, DIL-20 | — | Datasheet (https://www.reichelt.de/de/de/shop/produkt/latch_3-state_2_6_v_dil-20-3206)
U7, U8 | 2 | IC SRAM AS6C4008-55PCN | SRAM, 4 Mb (512 K x 8), 4.5 … 5.5 V, PDIP-32 | H11 | Datasheet 1 (https://www.alliancememory.com/wp-content/uploads/pdf/AS6C4008.pdf) · Datasheet 2 (https://www.reichelt.de/de/de/shop/produkt/sram_4_mb_512_k_x_8_4_5_5_5_v_pdip-32-40090)

### i-meic-pico_V6 Board

DOS PC with an 8088 single-board computer (SBC) https://github.com/DerHobbyEntwickler/i-meic

Bill of Materials — i-meic-pico_V6 Board | https://github.com/DerHobbyEntwickler/i-meic | Page 2
Part | Qty | Value | Remarks | Note | Datasheet
U12 | 1 | RP2040 Pro Micro / Raspberry Pi Pico | RP2040 Pro Micro / Raspberry Pi Pico | H12 | RP2040 Pro Micro Raspberry Pi Pico development board (source: AliExpress)

Blue underlined entries in the "Datasheet" column are clickable links.

### i-meic-pico_V6 Board

DOS PC with an 8088 single-board computer (SBC) https://github.com/DerHobbyEntwickler/i-meic

Bill of Materials — i-meic-pico_V6 Board | https://github.com/DerHobbyEntwickler/i-meic | Page 3

## Notes on the bill of materials

H01 — 470uF/10V or 1000uF/10V
2× electrolytic capacitors used as decoupling capacitors. Values are not critical.

H02 — Ceramic capacitor, 1uF or 10uF
13× decoupling capacitors, values are not critical. For decades a 100 nF decoupling capacitor was used for every IC. Today, ceramic capacitors from 1 uF upward are very cheap. Recommendation: 10 uF is even better.

H03 / H07 — LEDs and their series resistors (carbon film, 1K / 6.8K / 2.2K)
In principle, the resistors listed here are the series (dropping) resistors for the various LEDs. They are classically calculated by subtracting the LED forward voltage from the supply voltage. The resulting voltage, together with a chosen LED current (e.g. 5 mA), is used to calculate the resistor value. In practice, LED quality and typical on-time also matter a great deal.
The two white LEDs (R2, R15) are very bright and need only very little current for normal operation, so a series resistor of 6.8K has proven sufficient here. R1 with 1K as the series resistor for the green UART LED, by contrast, is often somewhat dim – especially since the supply voltage here is only 3.6 V – or a super-bright green LED is used. The 2.2K series resistor for the four blue ITP3 LEDs (R4, R5, R6, R7) has proven itself in practice.

H04 — Diode 1N4001
The value and type of the diode are entirely uncritical.

H05 — Pin header
The various pin headers (with 2, 3 and 4 pins) can be cut from one long 40-pin header. Coloured headers improve orientation but are not strictly necessary.

H06 — Box header (ITP3 cable)
No further text is provided for this note in the source. These are the 10-pin, dual-row box headers (J_DS0…J_DS3) for the ITP3 cables.

H08 — Carbon-film resistors 10K
Pull-up resistors to ensure a constant voltage level. Resistor values are not critical (4.7K … 22K should meet the requirements).

H09 — 74HC00 and 74HC02
Standard 74-series logic. Also relatively uncritical (HC, HCT or LS are possible).

### i-meic-pico_V6 Board

DOS PC with an 8088 single-board computer (SBC) https://github.com/DerHobbyEntwickler/i-meic

Bill of Materials — i-meic-pico_V6 Board | https://github.com/DerHobbyEntwickler/i-meic | Page 4

H10 — CPU Intel 80C88 or compatible
The central CPU IC, the 8088, has become quite rare by now and is somewhat more expensive. Where possible, the CMOS variant should be preferred (lower power consumption, runs cooler). The NMOS variants should also be usable (but this has not yet been tested).
One more note: cheaper components are often available on AliExpress. They were frequently used in these prototypes. However, at least in part, these appear to be used goods. That is not a problem in itself. What can happen is that the contacts are more or less oxidised. If sockets are used (which is recommended), contact difficulties may occur during assembly. In that case, please clean the IC pins (with a glass-fibre pen, carefully with fine sandpaper, or carefully with a small file).

H11 — SRAM AS6C4008-55PCN or pin-compatible IC
Components from German suppliers (such as Reichelt Elektronik) were always of high quality and without complaints, but also noticeably more expensive. On AliExpress they can certainly be obtained more cheaply, but may then be of lower quality (see “One more note” under H10).

H12 — RP2040 Pro Micro / Raspberry Pi Pico
The RP2040 Pro Micro board is considerably smaller than the classic Raspberry Pi Pico. For this reason it was used for this board. Both boards contain an RP2040 and are software-compatible. The source for the RP2040 Pro Micro board is AliExpress.

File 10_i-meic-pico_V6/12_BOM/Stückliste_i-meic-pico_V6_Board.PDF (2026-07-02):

# Stückliste

### i-meic-pico_V6 Board

DOS-PC mit 8088-Einplatinencomputer (SBC)

Projekt: i-meic – Einplatinen-DOS-PC Stand: Juli 2026 / July 2026 https://github.com/DerHobbyEntwickler/i-meic

Stückliste i-meic-pico_V6 Board | https://github.com/DerHobbyEntwickler/i-meic | Seite 1

Rechnerkern: CPU Intel 80C88 + 2× SRAM AS6C4008 (je 512 KB, zusammen 1 MB max.)

Positionen: 22 · Bauteile gesamt: 56

Bauteil | Anzah l | Wert | Bemerkungen | Hinweis | Datenblatt
C1, C14 | 2 | 470uF/10V oder 1000uF/10V | Elektrolytkondensator, radial, D8,0 mm, P3,50 mm | H01 | Datenblatt (https://www.reichelt.de/de/de/shop/produkt/elko_radial_1_0_mf_10_v_105_c_low_esr-200069)
C2, C3, C4, C5, C6, C7, C8, C9, C10, C11, C12, C13, C18 | 13 | 1uF/50V oder 10uF/50V | monolithischer Keramik-Kondensator, Rastermaß 2,5 mm bis 5 mm | H02 | Datenblatt (https://www.conrad.de/de/p/tancap-ct4-0805y105m500a1-keramik-kondensator-tht-1-f-50-v-20-b-x-h-4-2-mm-x-25-mm-1-st-1578616.html)
D1 | 1 | LED Grün, UART | Leuchtdiode, 3 mm oder 5 mm | H03 | Datenblatt (https://www.reichelt.de/de/de/shop/produkt/led_3mm_bedrahtet_gruen_50_mcd_60_-361591)
D2, D17 | 2 | LED Weiß, SRAM | Leuchtdiode, 3 mm oder 5 mm | — | Datenblatt (https://www.reichelt.de/de/de/shop/produkt/led_3mm_bedrahtet_gruen_50_mcd_60_-361591)
D3, D4, D5, D6 | 4 | LED Blau, ITP3 | Leuchtdiode, 3 mm oder 5 mm | — | Datenblatt (https://www.reichelt.de/de/de/shop/produkt/led_3mm_bedrahtet_gruen_50_mcd_60_-361591)
D7, D8, D9, D10, D11 | 5 | 1N4001 | Diode 1N4001 | H04 | Datenblatt (https://www.reichelt.de/de/de/shop/produkt/gleichrichterdiode_50_v_1_a_do-41-1723)
J10 | 1 | Stecker für seriellen Adapter | Stiftleiste 2,54 mm, einreihig, 4 Stifte | H05 | Datenblatt (https://www.reichelt.de/de/de/shop/produkt/stiftleisten_2_54_mm_1x36_gerade-119890)
JP1 | 1 | Stecker für Jumper, 3 Stifte | Stiftleiste 2,54 mm, einreihig, 3 Stifte | — | Datenblatt (https://www.reichelt.de/de/de/shop/produkt/stiftleisten_2_54_mm_1x36_gerade-119890)
JP2 | 1 | Stecker für Jumper, 2 Stifte | Stiftleiste 2,54 mm, einreihig, 2 Stifte | — | Datenblatt (https://www.reichelt.de/de/de/shop/produkt/stiftleisten_2_54_mm_1x36_gerade-119890)
J_DS0, J_DS1, J_DS2, J_DS3 | 4 | Stecker für ITP3-Kabel, zweireihig | Wannenstecker, 10-polig, gerade, zweireihig | H06 | Datenblatt (https://www.reichelt.de/de/de/shop/produkt/wannenstecker_10-polig_gerade-22816)
R1 | 1 | 1K | Widerstand, Kohleschicht, 1,0 kOhm, 0207, 250 mW, 5 % | H07 | Datenblatt (https://www.reichelt.de/de/de/shop/produkt/widerstand_kohleschicht_1_0_kohm_0207_250_mw_5_-1315)
R2, R15 | 2 | 6,8K | Widerstand, Kohleschicht, 6,8 kOhm, 0207, 250 mW, 5 % | — | —
R4, R5, R6, R7 | 4 | 2,2K | Widerstand, Kohleschicht, 2,2 kOhm, 0207, 250 mW, 5 % | — | —
R8, R9, R11 | 3 | 10K | Widerstand, Kohleschicht, 10 kOhm, 0207, 250 mW, 5 % | H08 | —
SW2 | 1 | Reset-Taster | Kurzhubtaster, Printmontage, 1 Schließer, 12 x 12 x 4,3 mm | — | Datenblatt (https://www.reichelt.de/de/de/shop/produkt/kurzhubtaster_printmontage_1_schliesser_12_x_12_x_4_3_mm-424572)
U1 | 1 | IC 74HC00 | 4-fach 2-Eingangs-NAND-Gatter, 2 … 6 V, DIL-14 | H09 | Datenblatt (https://www.reichelt.de/de/de/shop/produkt/4-fach_2_eingangs-nand-gatter_2_6_v_dil-14-3119)
U2 | 1 | IC 74HC02 | NOR-Gatter, 2-Eingang, 2 … 6 V, DIL-14 | — | Datenblatt (https://www.reichelt.de/de/de/shop/produkt/nor-gate_2-input_2_6_v_dil-14-3121)
U3, U10, U13 | 3 | 8-Kanal-Bidirektionaler Logikpegelwandler (3,3V ↔ 5V) | 8-Kanal-bidirektionales Logikpegelwandler-Modul (3,3V ↔ 5V) | — | Datenblatt (https://www.ebay.de/itm/263540322019?chn=ps&_ul=DE&google_free_listing_action=view_item)
U4 | 1 | IC CPU 80C88 | CPU Intel 80C88 oder kompatibel | H10 | Datenblatt (https://datasheets.chipdb.org/Harris/80c88.pdf)
U5, U6 | 2 | IC 74HC373 | Latch, 3-State, 2 … 6 V, DIL-20 | — | Datenblatt (https://www.reichelt.de/de/de/shop/produkt/latch_3-state_2_6_v_dil-20-3206)
U7, U8 | 2 | IC SRAM AS6C4008-55PCN | SRAM, 4 Mb (512 K x 8), 4,5 … 5,5 V, PDIP-32 | H11 | Datenblatt 1 (https://www.alliancememory.com/wp-content/uploads/pdf/AS6C4008.pdf) · Datenblatt 2 (https://www.reichelt.de/de/de/shop/produkt/sram_4_mb_512_k_x_8_4_5_5_5_v_pdip-32-40090)

### i-meic-pico_V6 Board

DOS-PC mit 8088-Einplatinencomputer (SBC) https://github.com/DerHobbyEntwickler/i-meic

Stückliste i-meic-pico_V6 Board | https://github.com/DerHobbyEntwickler/i-meic | Seite 2
Bauteil | Anzah l | Wert | Bemerkungen | Hinweis | Datenblatt
U12 | 1 | RP2040 Pro Micro / Raspberry Pi Pico | RP2040 Pro Micro / Raspberry Pi Pico | H12 | RP2040 Pro Micro Raspberry Pi Pico Development Board (Bezug: AliExpress)

Blau unterstrichene Einträge in der Spalte „Datenblatt“ sind anklickbare Links.

### i-meic-pico_V6 Board

DOS-PC mit 8088-Einplatinencomputer (SBC) https://github.com/DerHobbyEntwickler/i-meic

Stückliste i-meic-pico_V6 Board | https://github.com/DerHobbyEntwickler/i-meic | Seite 3

## Hinweise zur Stückliste

H01 — 470uF/10V oder 1000uF/10V
2× Elektrolytkondensator, Stützkondensatoren. Werte unkritisch.

H02 — Keramik-Kondensator, 1uF oder 10uF
13× Stützkondensatoren, Werte unkritisch. In den letzten Jahrzehnten verwendete man für jeden IC einen Stützkondensator von 100 nF. Heutzutage sind Keramik-Kondensatoren ab 1 uF sehr günstig. Empfehlung: 10 uF sind noch besser.

H03 / H07 — LEDs und ihre Vorwiderstände (Kohleschicht, 1K / 6,8K / 2,2K)
Grundsätzlich sind die hier angegebenen Widerstände die Vorwiderstände für diverse Leuchtdioden. Sie werden klassischerweise berechnet, indem die Versorgungsspannung minus die Flussspannung der LED gerechnet wird. Die daraus resultierende Spannung dient bei vorgegebenem Strom durch die Leuchtdiode (z. B. 5 mA) zur Berechnung des Widerstandes. Die Praxis zeigt, dass die Qualität der Leuchtdioden und die typische Leuchtdauer ebenfalls sehr wichtig sind.
So sind die beiden weißen LEDs (R2, R15) sehr hell und benötigen nur sehr wenig Strom zum regulären Betrieb. Daher hat sich hier der Vorwiderstand von 6,8K als ausreichend bewährt. R1 mit 1K als Vorwiderstand für die grüne UART-LED ist hingegen oft etwas dunkel, zumal die Versorgungsspannung hier nur 3,6 V beträgt – oder es wird eine superhelle grüne LED genutzt. Der Vorwiderstand von 2,2K für die 4 blauen ITP3-LEDs (R4, R5, R6, R7) hat sich in der Praxis bewährt.

H04 — Diode 1N4001
Wert und Typ der Diode sind vollkommen unkritisch.

H05 — Stiftleiste
Die diversen Stiftleisten (mit 2, 3 und 4 Stiften) können von einer langen 40-poligen Stiftleiste abgeschnitten werden. Farbige Stiftleisten verbessern die Orientierung, sind aber nicht unbedingt erforderlich.

H06 — Wannenstecker (ITP3-Kabel)
In der Vorlage ist zu diesem Hinweis kein weiterer Text hinterlegt. Es handelt sich um die 10-poligen, zweireihigen Wannenstecker (J_DS0…J_DS3) für die ITP3-Kabel.

H08 — Kohleschichtwiderstände 10K
Pull-up-Widerstände zum Gewährleisten eines konstanten Spannungspegels. Widerstandswerte sind unkritisch (4,7K … 22K sollten den Anforderungen genügen).

H09 — 74HC00 und 74HC02
Standard-74er-Baureihe. Ebenfalls relativ unkritisch (HC, HCT oder LS möglich).

### i-meic-pico_V6 Board

DOS-PC mit 8088-Einplatinencomputer (SBC) https://github.com/DerHobbyEntwickler/i-meic

Stückliste i-meic-pico_V6 Board | https://github.com/DerHobbyEntwickler/i-meic | Seite 4

H10 — CPU Intel 80C88 oder kompatibel
Der zentrale CPU-IC 8088 ist inzwischen schon recht selten geworden und etwas teurer. Wenn möglich sollte die CMOS-Variante bevorzugt werden (weniger Energieverbrauch und wird nicht so warm). Aber auch die NMOS-Varianten sollten nutzbar sein (ist aber noch nicht getestet worden).
Noch ein Hinweis: Bei AliExpress sind oft günstigere Bauelemente beziehbar. In diesen Prototypen wurden sie oft genutzt. Es scheint sich hier (zumindest teilweise) um gebrauchte Ware zu handeln. Das ist nicht weiter kritisch. Was dann vorkommen kann: Die Kontakte sind mehr oder weniger oxidiert. Wenn Fassungen genutzt werden (was zu empfehlen ist), kann es beim Einbau zu Kontaktschwierigkeiten kommen. Dann bitte die IC-Anschlüsse reinigen (mit Glasfaserstift, vorsichtig mit feinem Sandpapier oder vorsichtig mit einer kleinen Feile).

H11 — SRAM AS6C4008-55PCN oder pinkompatibler IC
Die Bauelemente von deutschen Lieferanten (wie z. B. Reichelt Elektronik) waren immer qualitativ hochwertig und ohne Beanstandungen, dafür aber auch deutlich teurer. Bei AliExpress bekommt man sie sicher günstiger, sie können dann aber auch eine geringere Qualität aufweisen (siehe „Noch ein Hinweis“ unter H10).

H12 — RP2040 Pro Micro / Raspberry Pi Pico
Das Board RP2040 Pro Micro ist wesentlich kleiner als der klassische Raspberry Pi Pico. Aus diesem Grund wurde es für dieses Board genutzt. Beide Boards enthalten einen RP2040 und sind softwareseitig funktionskompatibel. Bezugsquelle für das RP2040 Pro Micro Board ist AliExpress.

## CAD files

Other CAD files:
10_i-meic-pico_V6/20_Lazarus_PICO_i-meic-pico_V6_DOS/units/boot2_adafruit_itsybitsy_rp2040.obj
10_i-meic-pico_V6/20_Lazarus_PICO_i-meic-pico_V6_DOS/units/flash.c-debug.obj
10_i-meic-pico_V6/20_Lazarus_PICO_i-meic-pico_V6_DOS/units/multicore.c-debug.obj
10_i-meic-pico_V6/20_Lazarus_PICO_i-meic-pico_V6_DOS/units/gpio.c-debug.obj
10_i-meic-pico_V6/20_Lazarus_PICO_i-meic-pico_V6_DOS/units/timeout_helper.c-debug.obj
10_i-meic-pico_V6/20_Lazarus_PICO_i-meic-pico_V6_DOS/units/spi.c-debug.obj
10_i-meic-pico_V6/20_Lazarus_PICO_i-meic-pico_V6_DOS/units/clocks.c-debug.obj
10_i-meic-pico_V6/20_Lazarus_PICO_i-meic-pico_V6_DOS/units/boot2_pimoroni_tiny2040.obj
10_i-meic-pico_V6/20_Lazarus_PICO_i-meic-pico_V6_DOS/units/platform.c-debug.obj
10_i-meic-pico_V6/20_Lazarus_PICO_i-meic-pico_V6_DOS/units/boot2_adafruit_feather_rp2040.obj
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

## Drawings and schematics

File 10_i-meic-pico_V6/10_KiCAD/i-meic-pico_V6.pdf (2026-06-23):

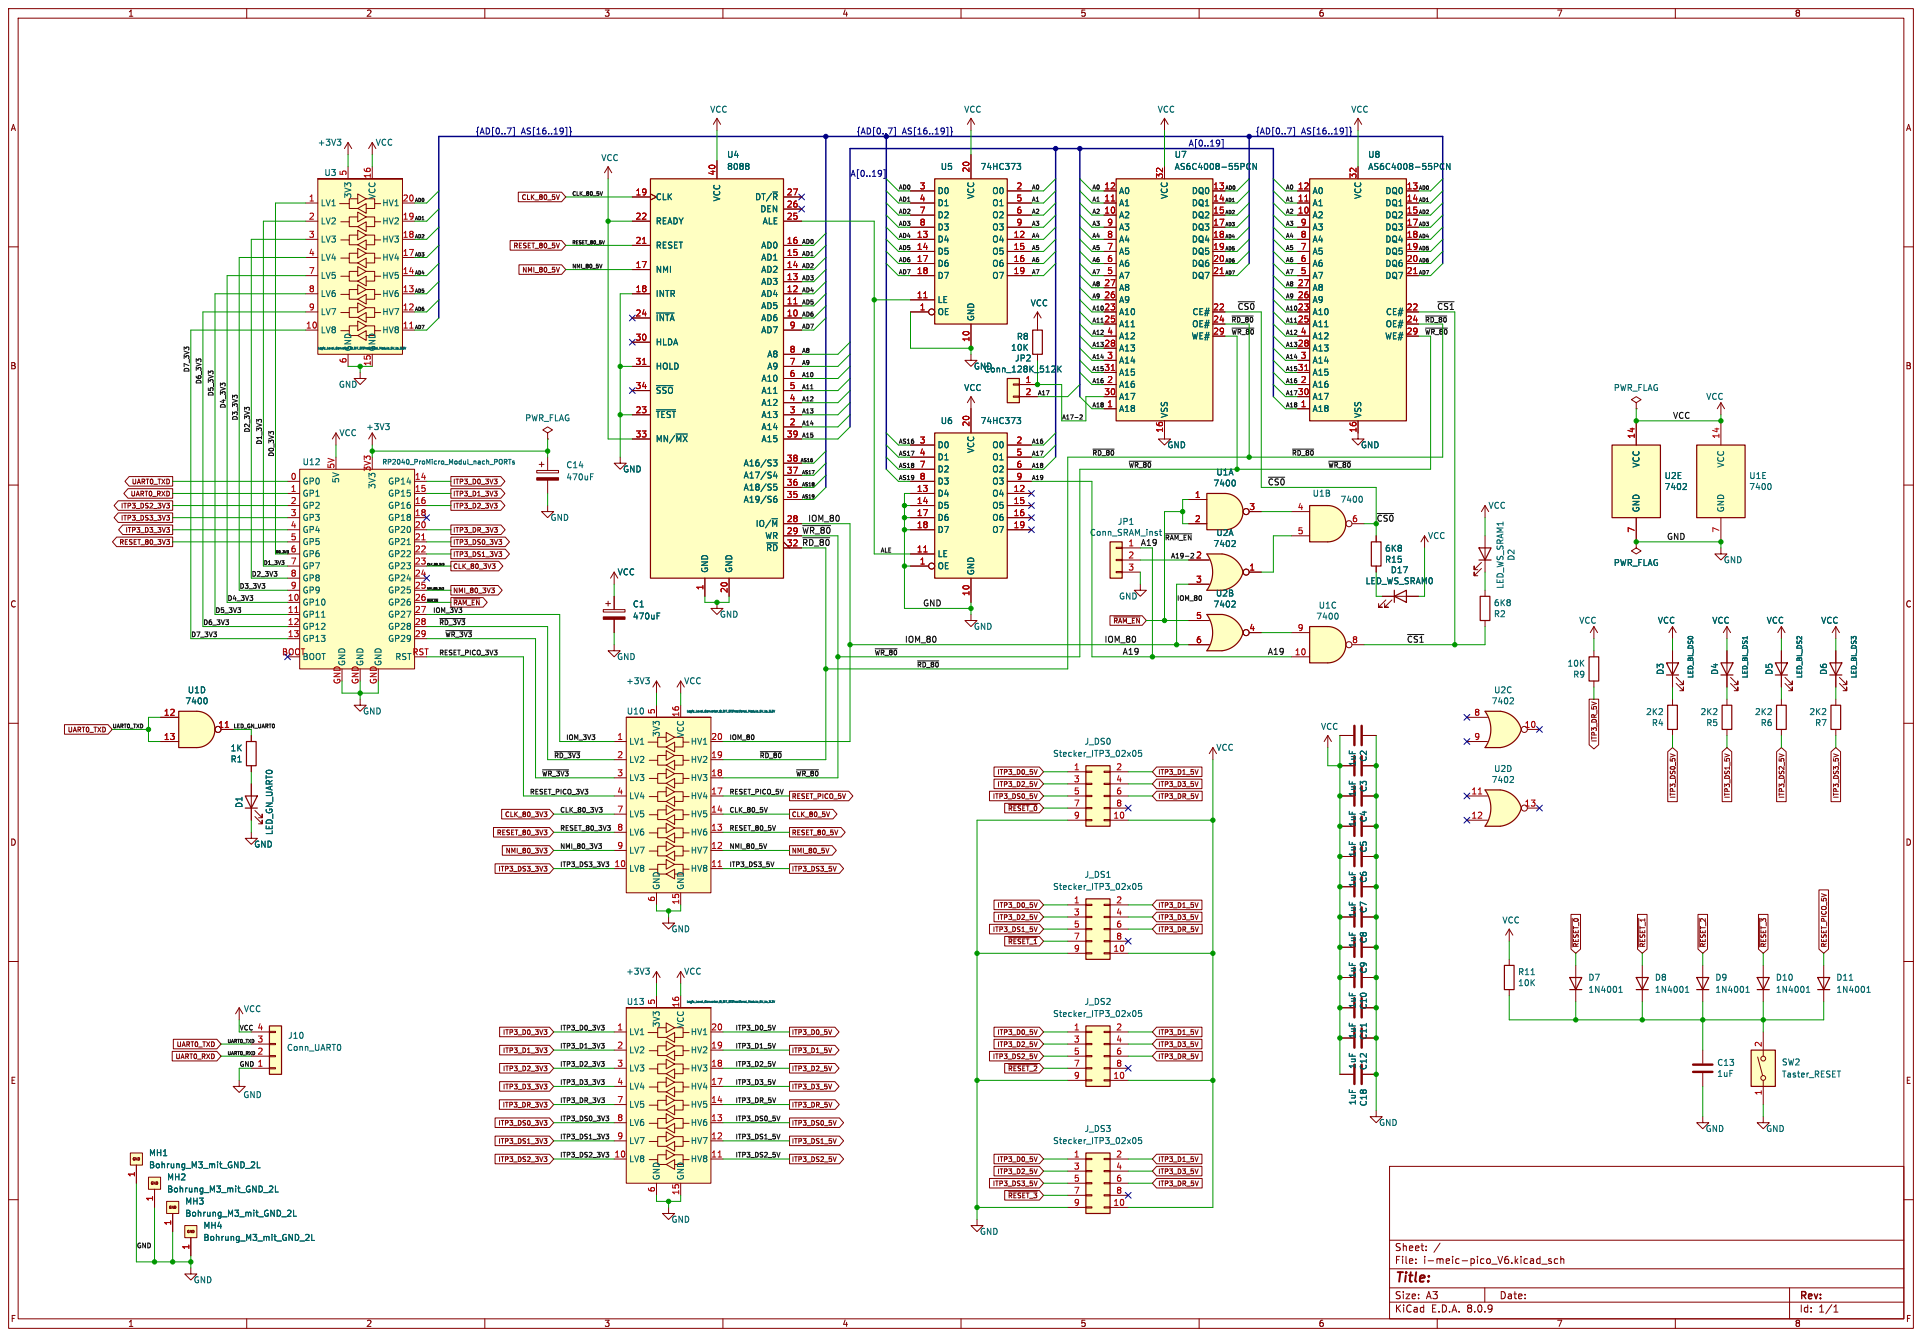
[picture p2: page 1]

Id: 1/1 Title: File: i-meic-pico_V6.kicad_sch Sheet: /

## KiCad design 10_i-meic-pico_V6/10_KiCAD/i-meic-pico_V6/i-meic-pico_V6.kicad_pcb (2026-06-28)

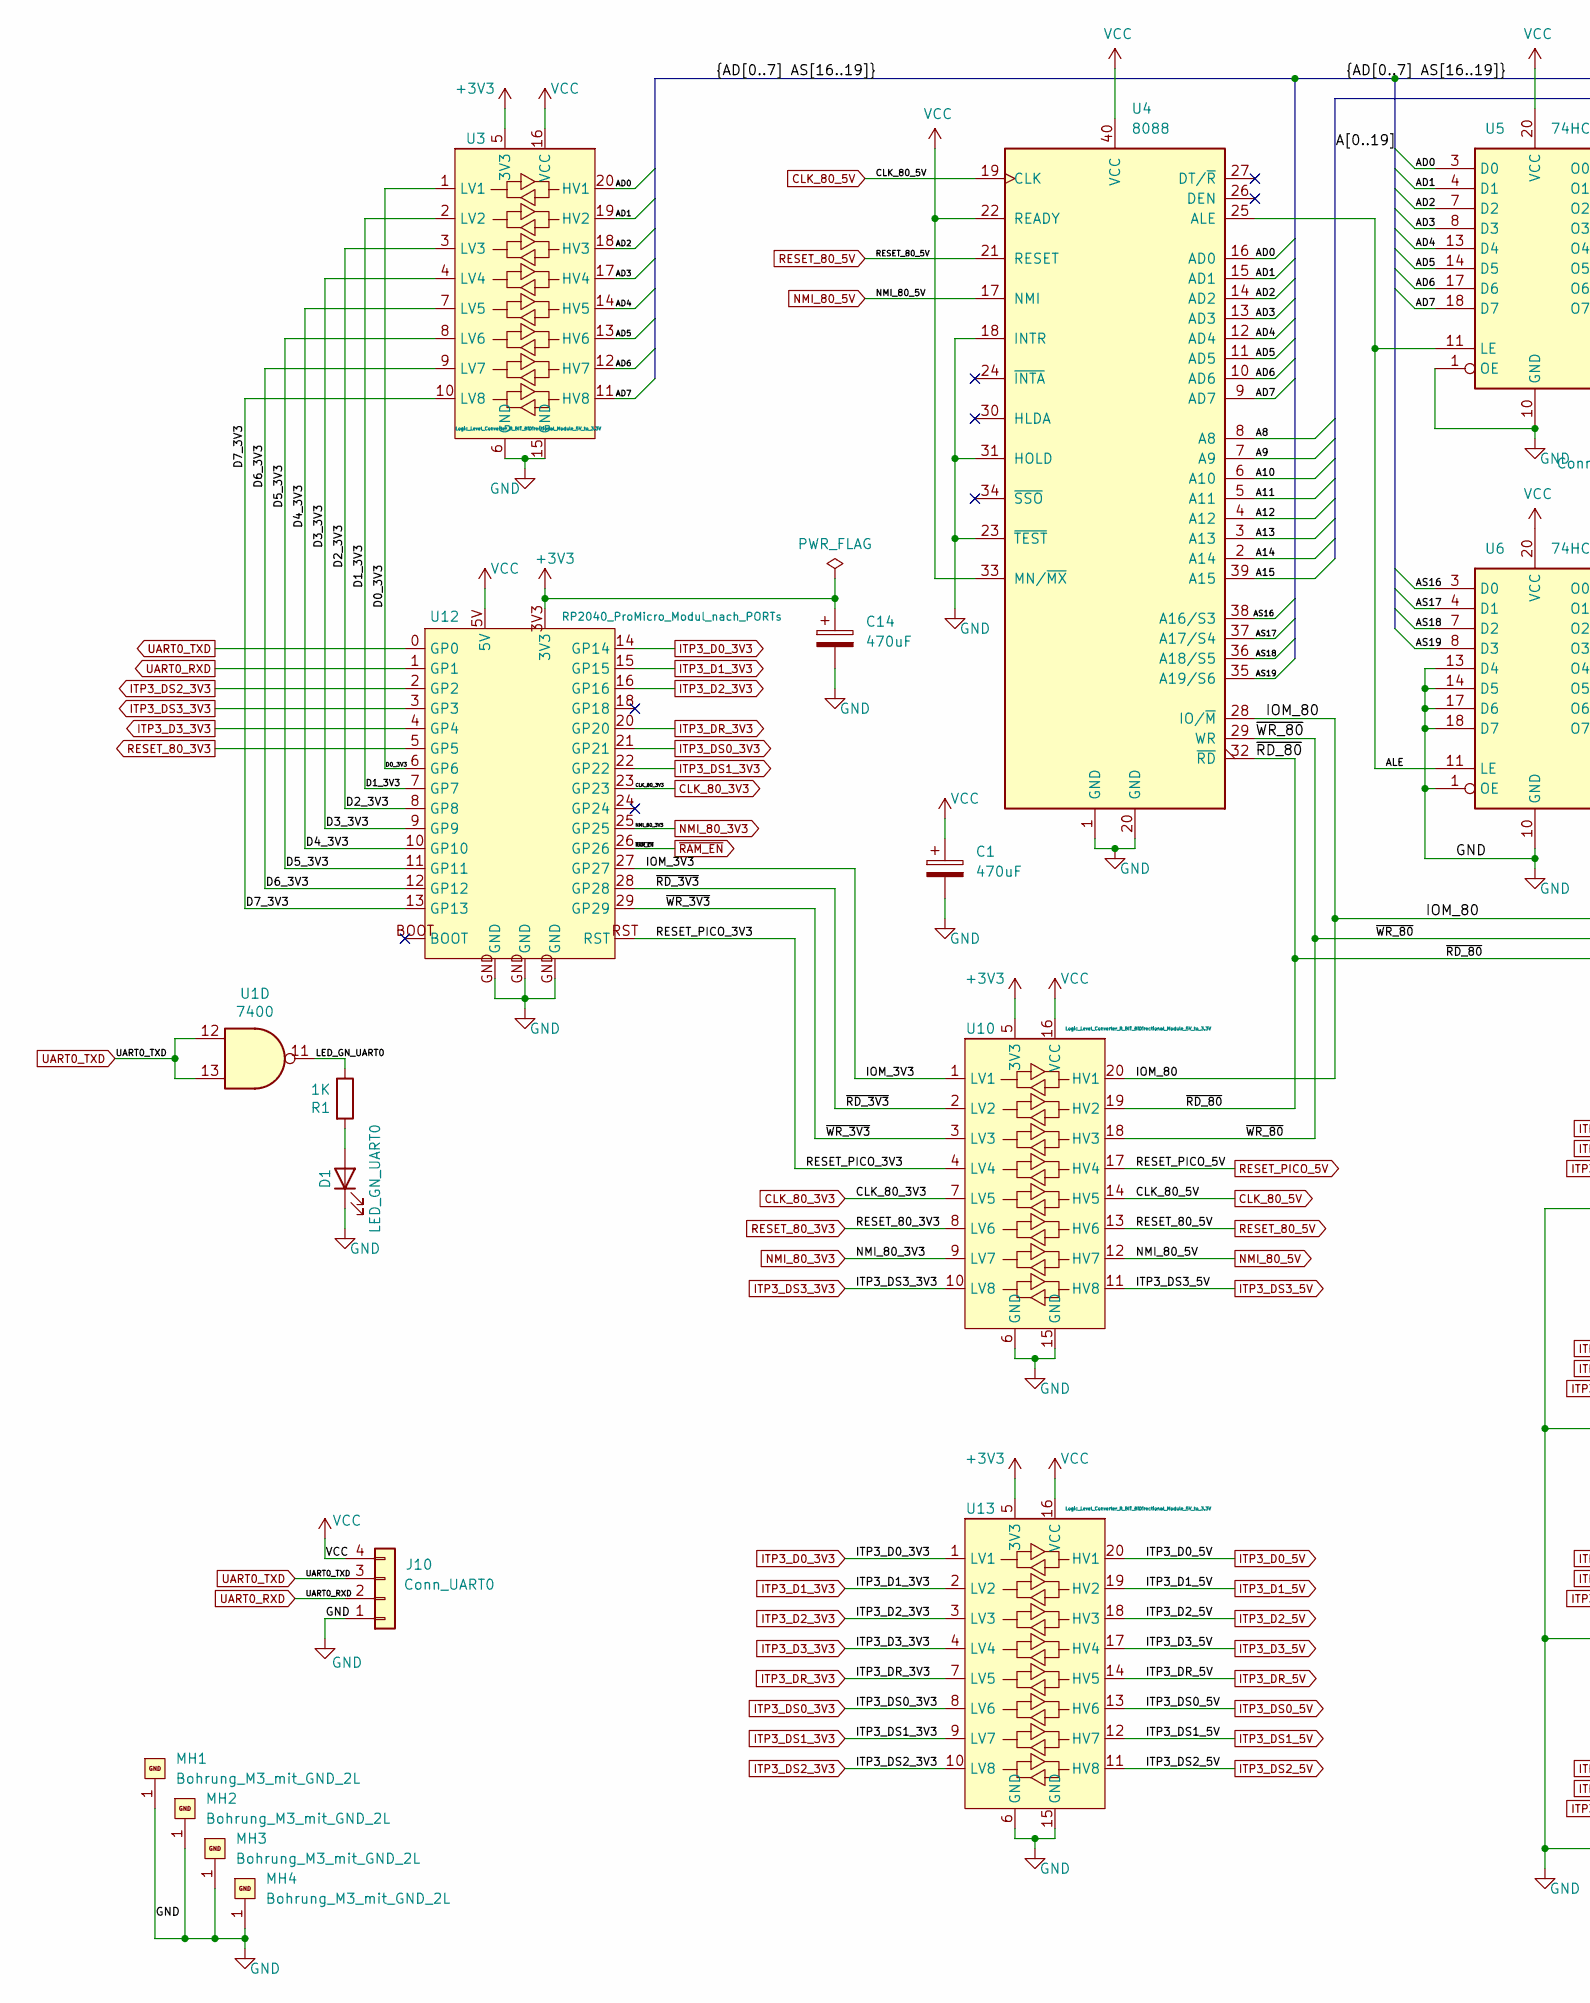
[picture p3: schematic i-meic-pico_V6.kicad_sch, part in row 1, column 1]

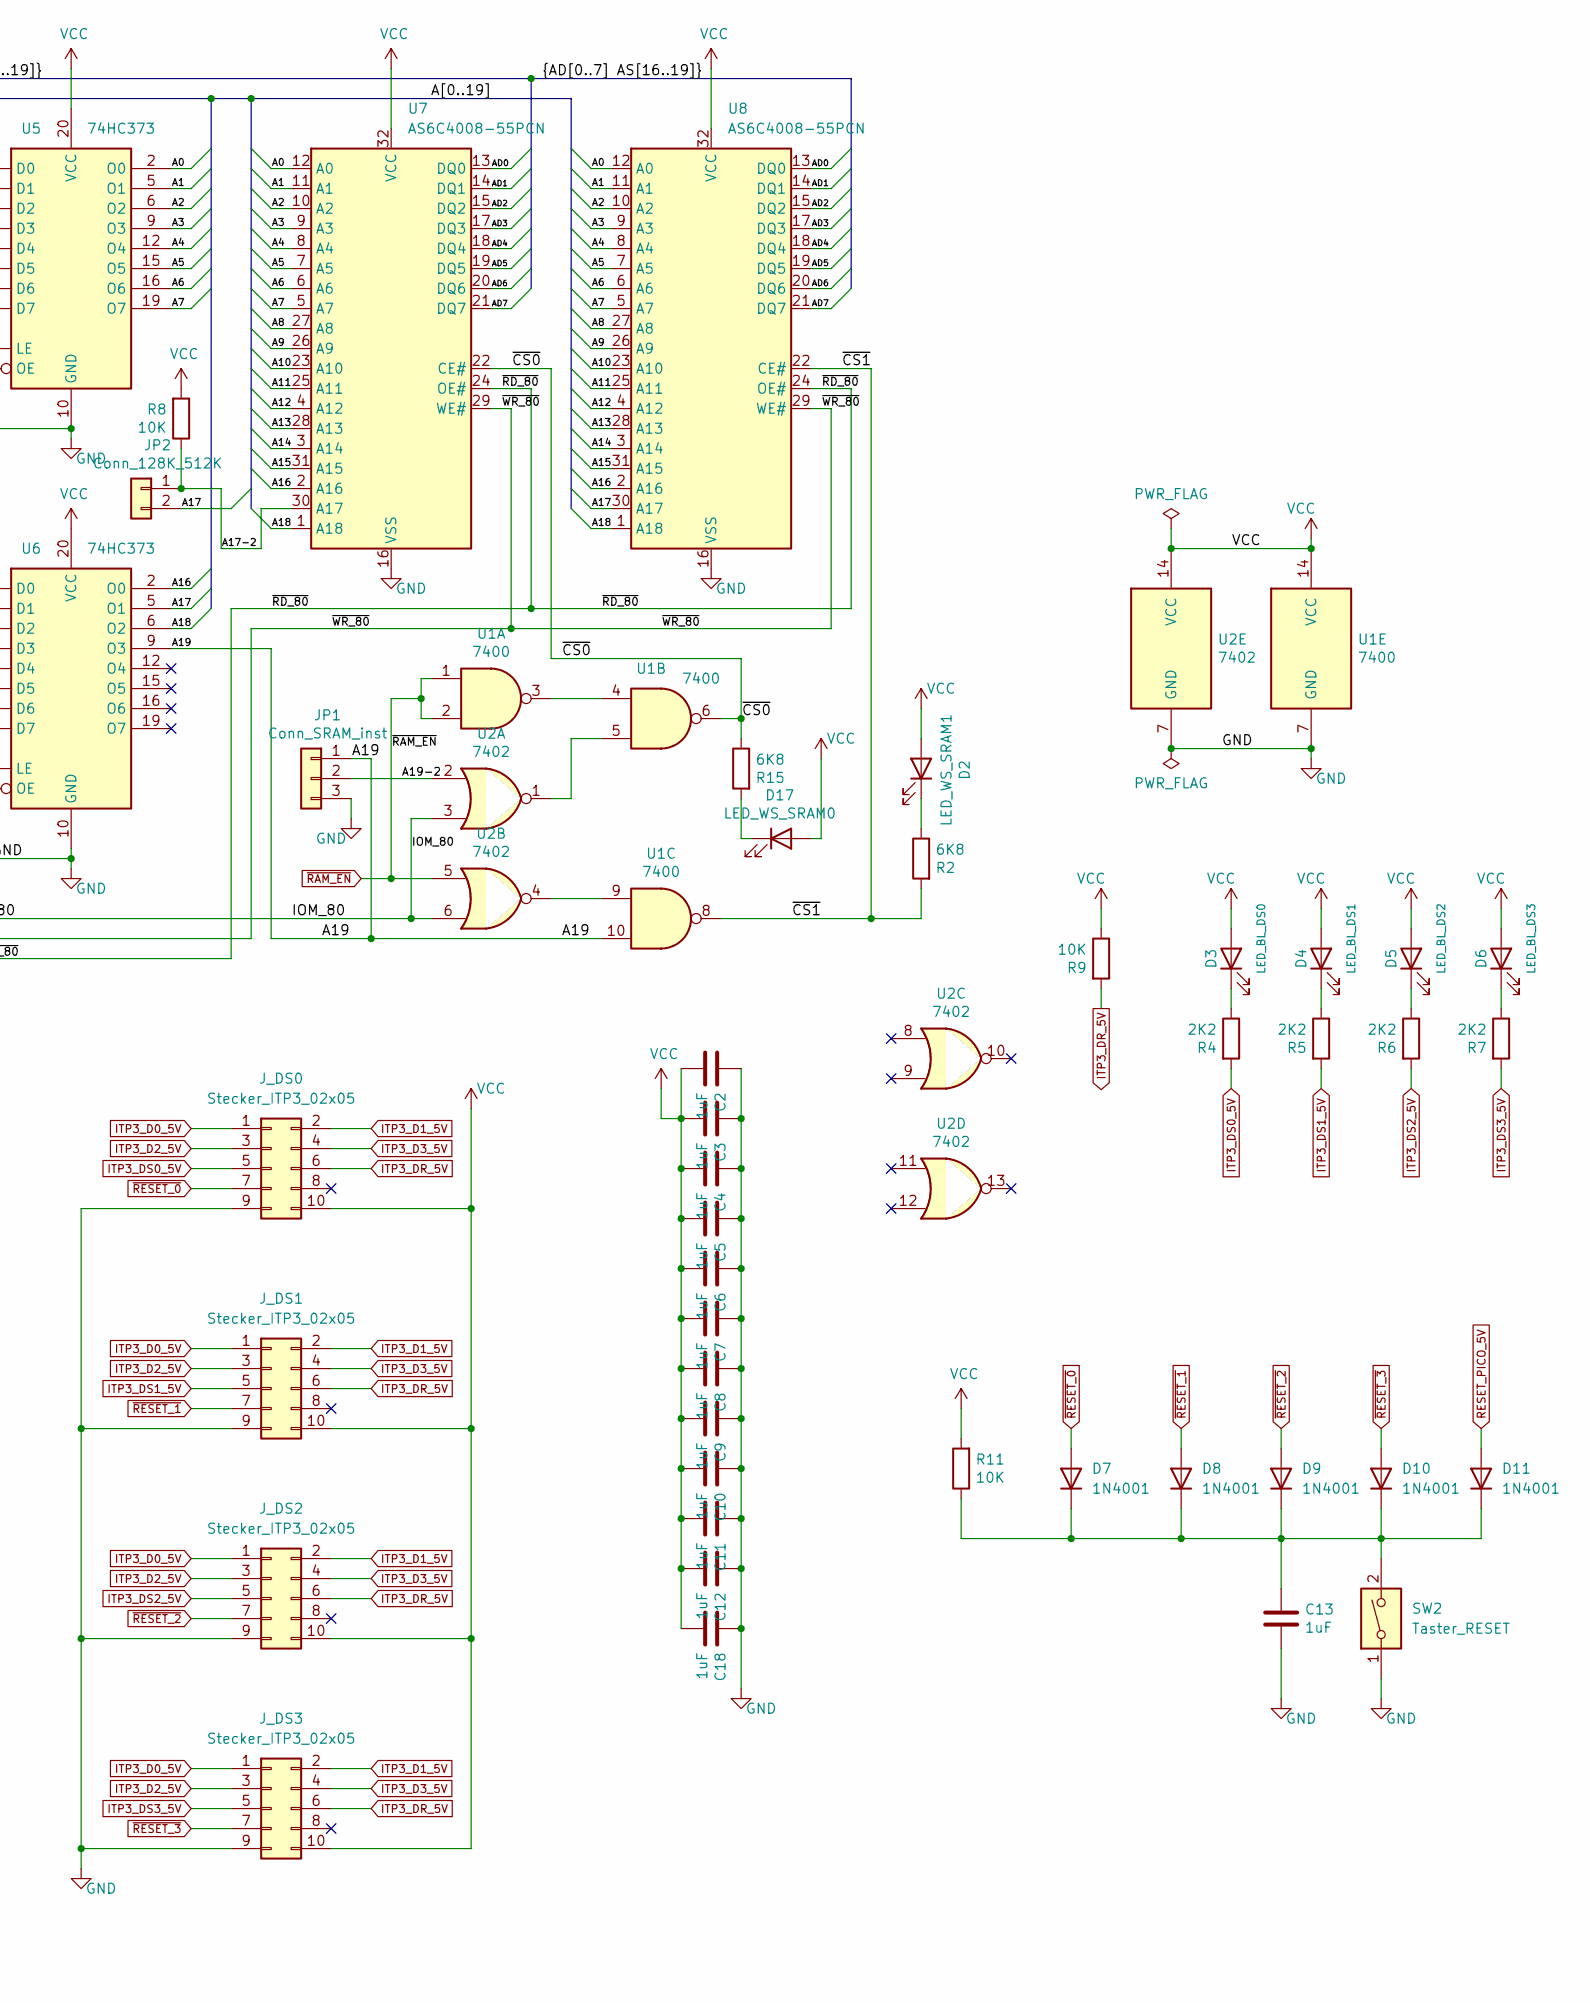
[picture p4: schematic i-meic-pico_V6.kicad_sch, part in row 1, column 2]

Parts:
C1, C14: 470uF; CP_470uF_Radial_D8.0mm_P3.50mm
C2, C3, C4, C5, C6, C7, C8, C9, C10, C11, C12, C13, C18: 1uF; C_Disc_D5.0mm_W2.5mm_P5.00mm_2
D1: LED_GN_UART0; LED_D3.0mm
D2: LED_WS_SRAM1; LED_D3.0mm
D3: LED_BL_DS0; LED_D3.0mm
D4: LED_BL_DS1; LED_D3.0mm
D5: LED_BL_DS2; LED_D3.0mm
D6: LED_BL_DS3; LED_D3.0mm
D7, D8, D9, D10, D11: 1N4001; Diode_1N4001
D17: LED_WS_SRAM0; LED_D3.0mm
J10: Conn_UART0; PinHeader_1x04_P2.54mm_Vertical
JP1: Conn_SRAM_inst; PinHeader_1x03_P2.54mm_Vertical
JP2: Conn_128K_512K; PinHeader_1x02_P2.54mm_Vertical
J_DS0, J_DS1, J_DS2, J_DS3: Stecker_ITP3_02x05; Stecker_ITP3_2x05_RM_2.54mm_Vertical
MH1, MH2, MH3, MH4: Bohrung_M3_mit_GND_2L; Bohrung_M3_mit_GND
R1: 1K; R_Axial_DIN0204_L3.6mm_D1.6mm_P7.62mm_Horizontal
R2, R15: 6K8; R_Axial_DIN0204_L3.6mm_D1.6mm_P7.62mm_Horizontal
R4, R5, R6, R7: 2K2; R_Axial_DIN0204_L3.6mm_D1.6mm_P7.62mm_Horizontal
R8, R9, R11: 10K; R_Axial_DIN0204_L3.6mm_D1.6mm_P7.62mm_Horizontal
SW2: Taster_RESET; Schalter_Taster_PUSH-12,55mm_und_6,5mm
U1: 7400; DIP-14_W7.62mm
U2: 7402; DIP-14_W7.62mm
U3, U10, U13: Logic_Level_Converter_8_BIT_BiDirectional_Module_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; Logic_Level_Converter_8Bit_BiDirectional_Module_5V_to_3.3V
U4: 8088; DIP-40_W15.24mm
U5, U6: 74HC373; DIP-20_W7.62mm
U7, U8: AS6C4008-55PCN; DIP-32_W15.24mm
U12: RP2040_ProMicro_Modul_nach_PORTs; RP2040_ProMicro_Modul

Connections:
+3V3: C14.1, U3.5 (3V3), U10.5 (3V3), U12.3V3, U13.5 (3V3)
/A0: U5.2 (O0), U7.12 (A0), U8.12 (A0)
/A1: U5.5 (O1), U7.11 (A1), U8.11 (A1)
/A2: U5.6 (O2), U7.10 (A2), U8.10 (A2)
/A3: U5.9 (O3), U7.9 (A3), U8.9 (A3)
/A4: U5.12 (O4), U7.8 (A4), U8.8 (A4)
/A5: U5.15 (O5), U7.7 (A5), U8.7 (A5)
/A6: U5.16 (O6), U7.6 (A6), U8.6 (A6)
/A7: U5.19 (O7), U7.5 (A7), U8.5 (A7)
/A8: U4.8 (A8), U7.27 (A8), U8.27 (A8)
/A9: U4.7 (A9), U7.26 (A9), U8.26 (A9)
/A10: U4.6 (A10), U7.23 (A10), U8.23 (A10)
/A11: U4.5 (A11), U7.25 (A11), U8.25 (A11)
/A12: U4.4 (A12), U7.4 (A12), U8.4 (A12)
/A13: U4.3 (A13), U7.28 (A13), U8.28 (A13)
/A14: U4.2 (A14), U7.3 (A14), U8.3 (A14)
/A15: U4.39 (A15), U7.31 (A15), U8.31 (A15)
/A16: U6.2 (O0), U7.2 (A16), U8.2 (A16)
/A17: JP2.2, U6.5 (O1), U8.30 (A17)
/A17-2: JP2.1, R8.1, U7.30 (A17)
/A18: U6.6 (O2), U7.1 (A18), U8.1 (A18)
/A19: JP1.1, U1.10, U6.9 (O3)
/A19-2: JP1.2, U2.2
/AD0: U3.20 (HV1), U4.16 (AD0), U5.3 (D0), U7.13 (DQ0), U8.13 (DQ0)
/AD1: U3.19 (HV2), U4.15 (AD1), U5.4 (D1), U7.14 (DQ1), U8.14 (DQ1)
/AD2: U3.18 (HV3), U4.14 (AD2), U5.7 (D2), U7.15 (DQ2), U8.15 (DQ2)
/AD3: U3.17 (HV4), U4.13 (AD3), U5.8 (D3), U7.17 (DQ3), U8.17 (DQ3)
/AD4: U3.14 (HV5), U4.12 (AD4), U5.13 (D4), U7.18 (DQ4), U8.18 (DQ4)
/AD5: U3.13 (HV6), U4.11 (AD5), U5.14 (D5), U7.19 (DQ5), U8.19 (DQ5)
/AD6: U3.12 (HV7), U4.10 (AD6), U5.17 (D6), U7.20 (DQ6), U8.20 (DQ6)
/AD7: U3.11 (HV8), U4.9 (AD7), U5.18 (D7), U7.21 (DQ7), U8.21 (DQ7)
/ALE: U4.25 (ALE), U5.11 (LE), U6.11 (LE)
/AS16: U4.38 (A16/S3), U6.3 (D0)
/AS17: U4.37 (A17/S4), U6.4 (D1)
/AS18: U4.36 (A18/S5), U6.7 (D2)
/AS19: U4.35 (A19/S6), U6.8 (D3)
/D0_3V3: U3.1 (LV1), U12.6 (GP6)
/D1_3V3: U3.2 (LV2), U12.7 (GP7)
/D2_3V3: U3.3 (LV3), U12.8 (GP8)
/D3_3V3: U3.4 (LV4), U12.9 (GP9)
/D4_3V3: U3.7 (LV5), U12.10 (GP10)
/D5_3V3: U3.8 (LV6), U12.11 (GP11)
/D6_3V3: U3.9 (LV7), U12.12 (GP12)
/D7_3V3: U3.10 (LV8), U12.13 (GP13)
/IOM_3V3: U10.1 (LV1), U12.27 (GP27)
/IOM_80: U2.3, U2.6, U4.28 (IO/~M), U10.20 (HV1)
/LED_GN_UART0: R1.1, U1.11
/RESET_PICO_3V3: U10.4 (LV4), U12.RST
/~CS0: R15.1, U1.6, U7.22 (CE#)
/~CS1: R2.2, U1.8, U8.22 (CE#)
/~RD_3V3: U10.2 (LV2), U12.28 (GP28)
/~RD_80: U4.32 (~RD), U7.24 (OE#), U8.24 (OE#), U10.19 (HV2)
/~WR_3V3: U10.3 (LV3), U12.29 (GP29)
/~WR_80: U4.29 (WR), U7.29 (WE#), U8.29 (WE#), U10.18 (HV3)
CLK_80_3V3: U10.7 (LV5), U12.23 (GP23)
CLK_80_5V: U4.19 (CLK), U10.14 (HV5)
GND: C1.2, C2.1, C3.1, C4.1, C5.1, C6.1, C7.1, C8.1, C9.1, C10.1, C11.1, C12.1, C13.2, C14.2, C18.1, D1.1 (K), J10.1, JP1.3, J_DS0.9, J_DS1.9, J_DS2.9, J_DS3.9, MH1.1 (GND), MH2.1 (GND), MH3.1 (GND), MH4.1 (GND), SW2.1, U1.7 (GND), U2.7 (GND), U3.6 (GND), U3.15 (GND), U4.1 (GND), U4.18 (INTR), U4.20 (GND), U4.23 (~TEST), U4.31 (HOLD), U5.1 (OE), U5.10 (GND), U6.1 (OE), U6.10 (GND), U6.13 (D4), U6.14 (D5), U6.17 (D6), U6.18 (D7), U7.16 (VSS), U8.16 (VSS), U10.6 (GND), U10.15 (GND), U12.GND, U13.6 (GND), U13.15 (GND)
ITP3_D0_3V3: U12.14 (GP14), U13.1 (LV1)
ITP3_D0_5V: J_DS0.1, J_DS1.1, J_DS2.1, J_DS3.1, U13.20 (HV1)
ITP3_D1_3V3: U12.15 (GP15), U13.2 (LV2)
ITP3_D1_5V: J_DS0.2, J_DS1.2, J_DS2.2, J_DS3.2, U13.19 (HV2)
ITP3_D2_3V3: U12.16 (GP16), U13.3 (LV3)
ITP3_D2_5V: J_DS0.3, J_DS1.3, J_DS2.3, J_DS3.3, U13.18 (HV3)
ITP3_D3_3V3: U12.4 (GP4), U13.4 (LV4)
ITP3_D3_5V: J_DS0.4, J_DS1.4, J_DS2.4, J_DS3.4, U13.17 (HV4)
ITP3_DR_3V3: U12.20 (GP20), U13.7 (LV5)
ITP3_DR_5V: J_DS0.6, J_DS1.6, J_DS2.6, J_DS3.6, R9.2, U13.14 (HV5)
ITP3_DS0_3V3: U12.21 (GP21), U13.8 (LV6)
ITP3_DS0_5V: J_DS0.5, R4.2, U13.13 (HV6)
ITP3_DS1_3V3: U12.22 (GP22), U13.9 (LV7)
ITP3_DS1_5V: J_DS1.5, R5.2, U13.12 (HV7)
ITP3_DS2_3V3: U12.2 (GP2), U13.10 (LV8)
ITP3_DS2_5V: J_DS2.5, R6.2, U13.11 (HV8)
ITP3_DS3_3V3: U10.10 (LV8), U12.3 (GP3)
ITP3_DS3_5V: J_DS3.5, R7.2, U10.11 (HV8)
NMI_80_3V3: U10.9 (LV7), U12.25 (GP25)
NMI_80_5V: U4.17 (NMI), U10.12 (HV7)
unnamed: D1.2 (A), R1.2
unnamed: D2.1 (K), R2.1
unnamed: D3.1 (K), R4.1
unnamed: D4.1 (K), R5.1
unnamed: D5.1 (K), R6.1
unnamed: D6.1 (K), R7.1
unnamed: C13.1, D7.1 (K), D8.1 (K), D9.1 (K), D10.1 (K), D11.1 (K), R11.1, SW2.2
unnamed: D17.1 (K), R15.2
unnamed: U1.3, U1.4
unnamed: U1.5, U2.1
unnamed: U1.9, U2.4
RESET_80_3V3: U10.8 (LV6), U12.5 (GP5)
RESET_80_5V: U4.21 (RESET), U10.13 (HV6)
RESET_PICO_5V: D11.2 (A), U10.17 (HV4)
UART0_RXD: J10.2, U12.1 (GP1)
UART0_TXD: J10.3, U1.12, U1.13, U12.0 (GP0)
VCC: C1.1, C2.2, C3.2, C4.2, C5.2, C6.2, C7.2, C8.2, C9.2, C10.2, C11.2, C12.2, C18.2, D2.2 (A), D3.2 (A), D4.2 (A), D5.2 (A), D6.2 (A), D17.2 (A), J10.4, J_DS0.10, J_DS1.10, J_DS2.10, J_DS3.10, R8.2, R9.1, R11.2, U1.14 (VCC), U2.14 (VCC), U3.16 (VCC), U4.22 (READY), U4.33 (MN/~MX), U4.40 (VCC), U5.20 (VCC), U6.20 (VCC), U7.32 (VCC), U8.32 (VCC), U10.16 (VCC), U12.5V, U13.16 (VCC)
~RAM_EN: U1.1, U1.2, U2.5, U12.26 (GP26)
~RESET_0: D7.2 (A), J_DS0.7
~RESET_1: D8.2 (A), J_DS1.7
~RESET_2: D9.2 (A), J_DS2.7
~RESET_3: D10.2 (A), J_DS3.7

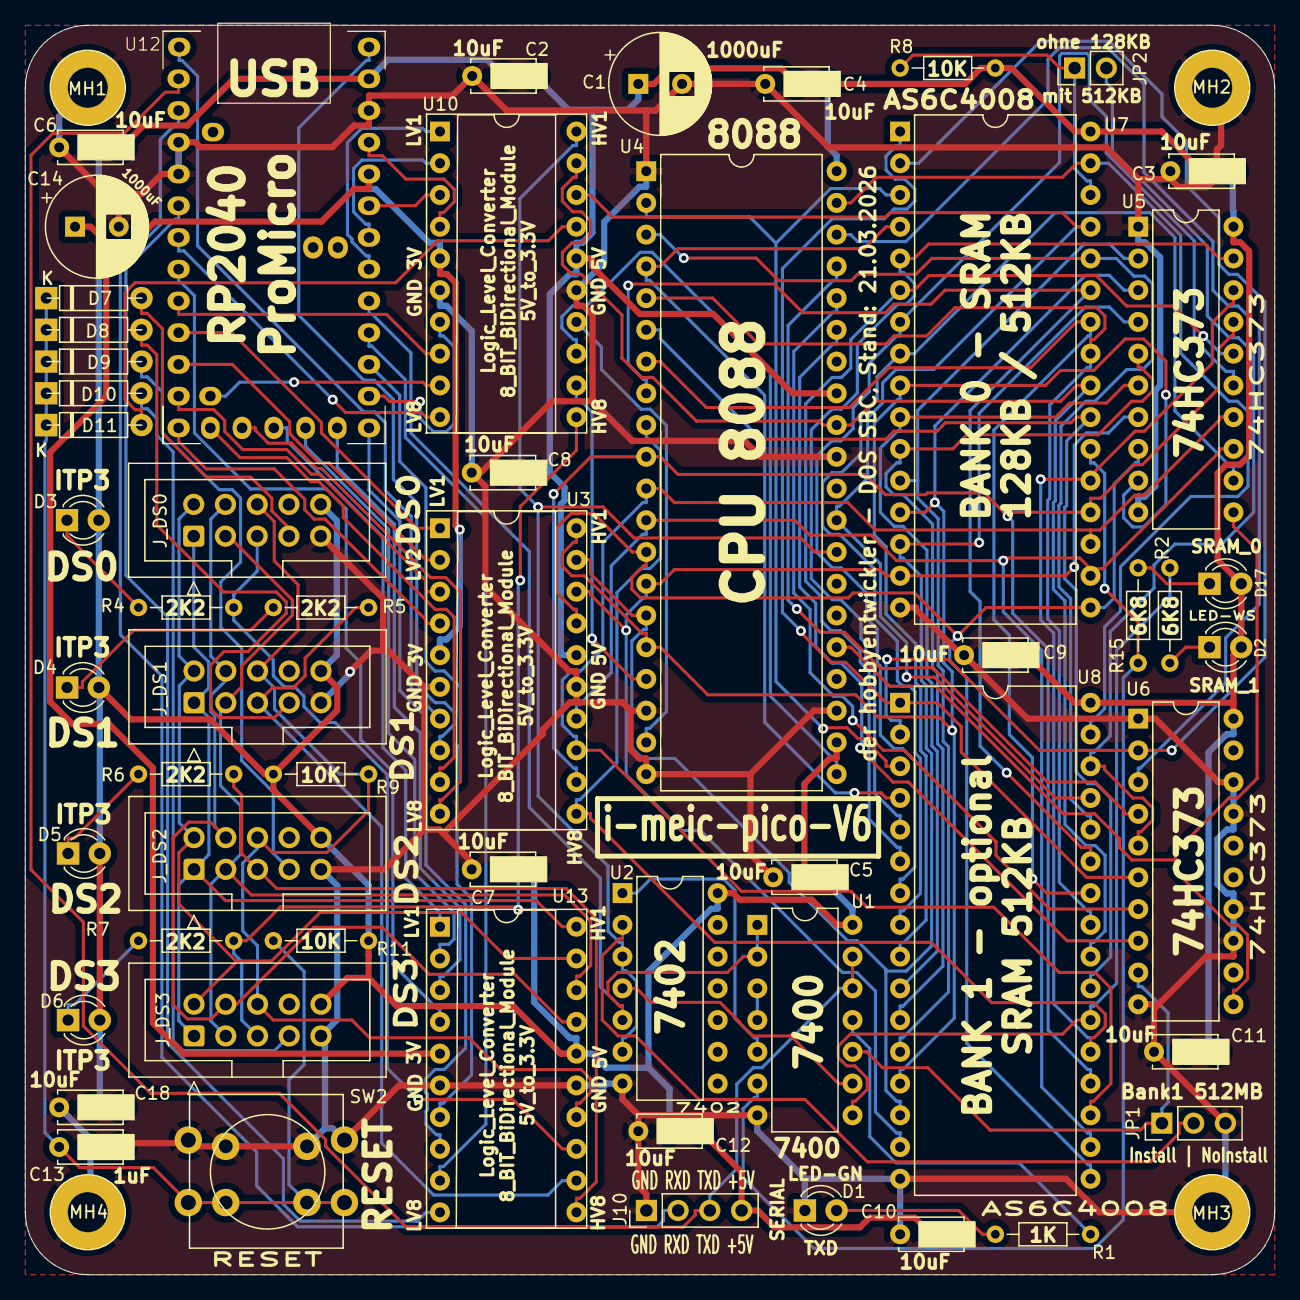
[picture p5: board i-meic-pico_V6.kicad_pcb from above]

Board: 2 copper layers, 100.0 x 100.0 mm, 60 parts (0 on the bottom side), 99 nets.

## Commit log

2026-06-28 Änderungen am 28.06.2026
    [adc.c-debug.obj, boot2_adafruit_feather_rp2040.obj, boot2_adafruit_itsybitsy_rp2040.obj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]
2026-06-28 change 28.06.2026 V2
    [adc.c-debug.obj, boot2_adafruit_feather_rp2040.obj, boot2_adafruit_itsybitsy_rp2040.obj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]
